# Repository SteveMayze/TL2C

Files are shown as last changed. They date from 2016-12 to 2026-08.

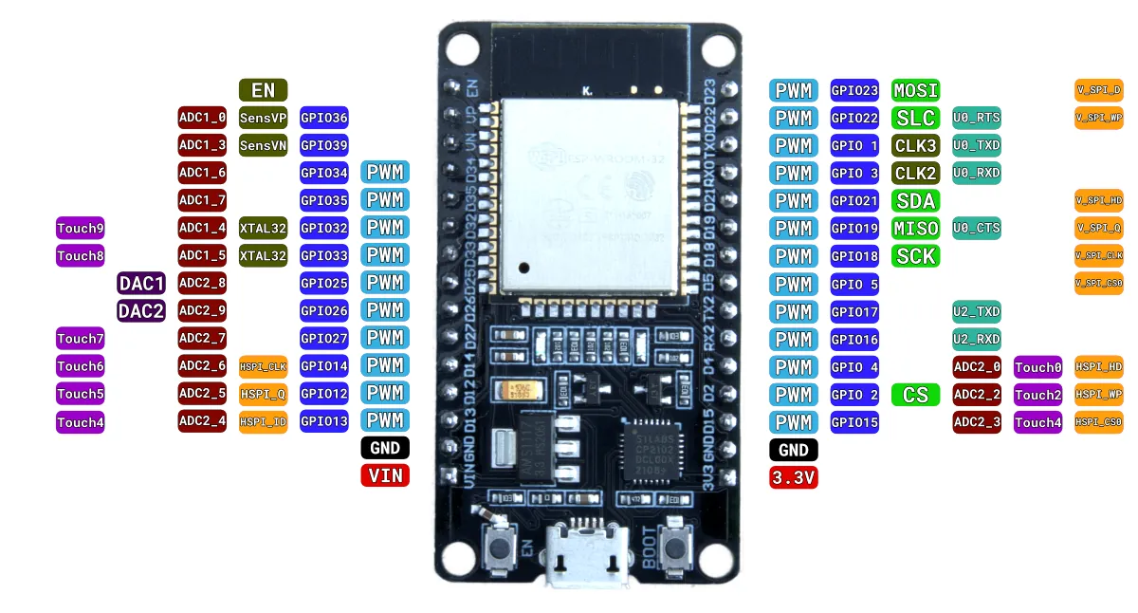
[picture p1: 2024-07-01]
doc/esp32/Node_MCU_ESP32_30Pin_pinout.webp

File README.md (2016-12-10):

# TL2C - Timed LED Lighting Control

## Introduction
This project is a I2C device to control up to three High Power LED drivers using three PIR13 motion controllers.

The LED drivers in question are already provided on my site and are the SLV 464110 10W 3-36V \(EAN: 4024163087155) constant current High Power LED drivers - as are the motion detectors [PIR13](http://www.elv.de/bewegungsmeldermodul-pir-13.html) modules from [ELV](http://www.elv.de).

The device will be designed around the ATTINY20-SSU micro-controller. The requirements being SPI for In System Programming, I2C to connect to the master device and GPIO for the three High Power LED drivers and the three PIR13 sensors.

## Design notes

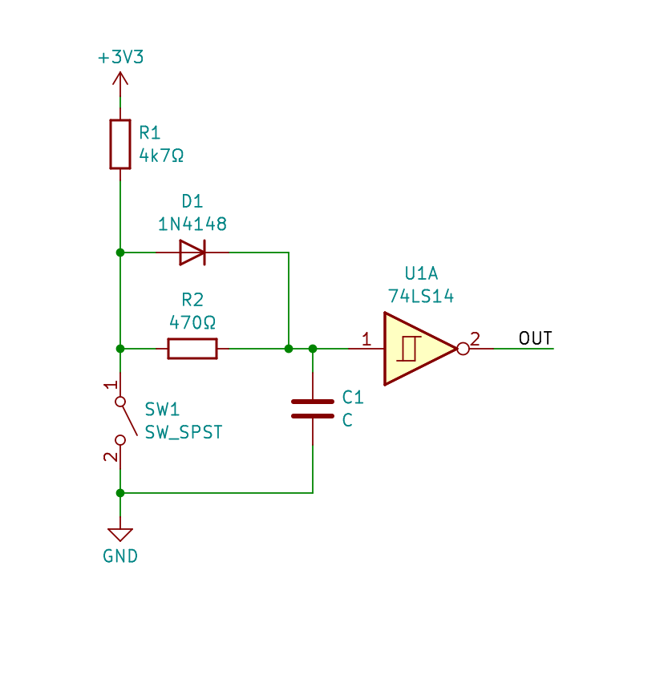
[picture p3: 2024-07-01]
doc/esp32/De-Bounce.png

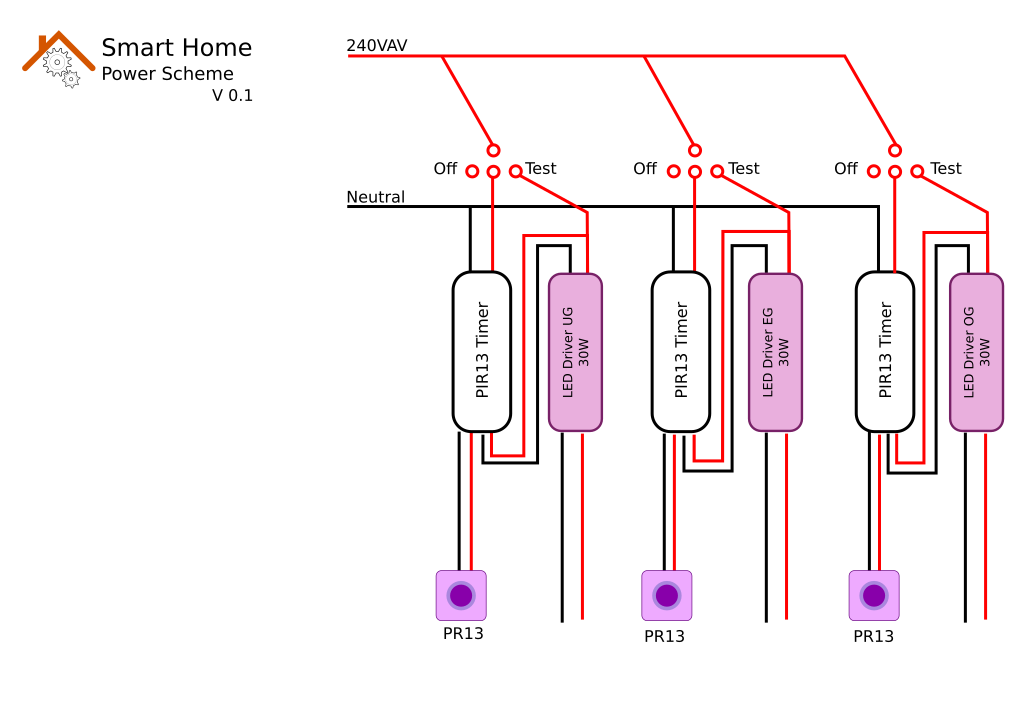
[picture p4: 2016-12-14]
doc/CurrentLEDControl.png

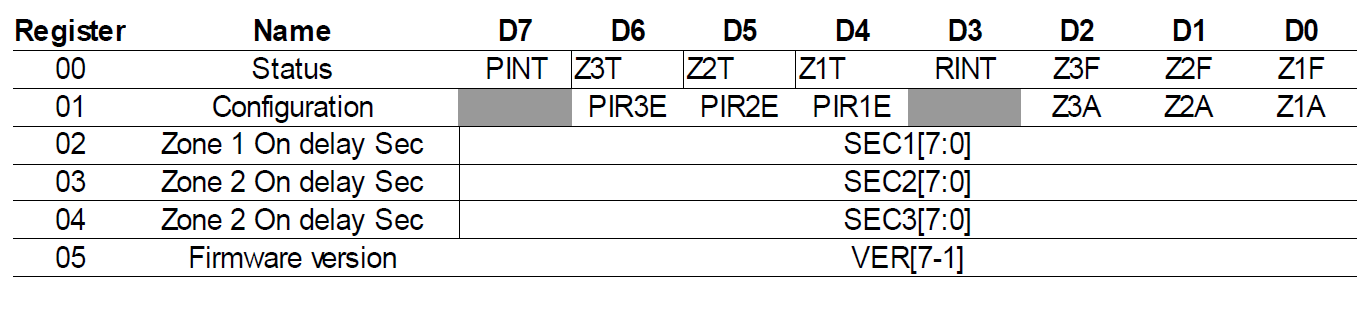
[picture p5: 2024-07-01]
doc/esp32/tl2c-registers.png

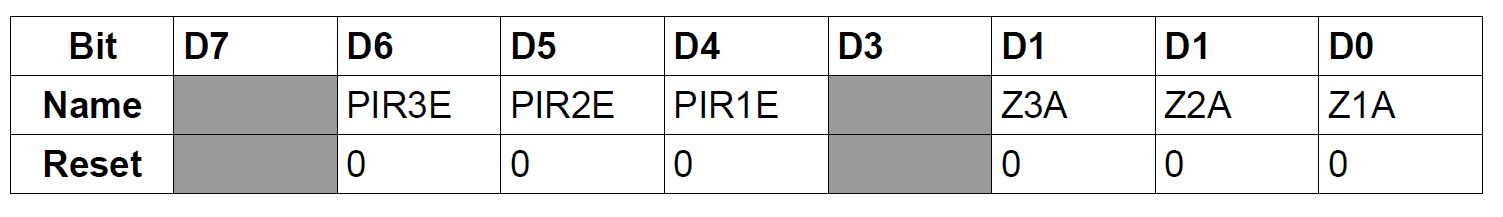
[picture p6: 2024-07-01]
doc/esp32/tl2c-register-1.png

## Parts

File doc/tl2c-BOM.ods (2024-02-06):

Reference | Quantity | Price | VAT | Cost | Conrad-PN | Digikey-PN | Reichelt-PN | MPN | ConradPN | Label
C101 C102 | 2 | 0.00052 | 1 | 0.00104
C201 | 1 | 0.00052 | 1 | 0.00052
C202 | 1 | 0.00052 | 1 | 0.00052
C203 | 1 | 0.27000 | 1 | 0.27000 | 450955 - 62 | N/A
C204 | 1 | 0.00052 | 1 | 0.00052
C501 C502 C503 | 3 | 0.00052 | 1 | 0.00156 |  |  |  | Value | Value
D101 | 1 | 0.13000 | 1 | 0.13000
D102 | 1 | 0.13000 | 1 | 0.13000
D103 | 1 | 0.13000 | 1 | 0.13000
D202 | 1 | 0.33000 | 1 | 0.33000
D404 D405 D406 | 3 | 0.17000 | 1 | 0.51000 | 564852 - 62 | 1N4148W-E3-18CT-ND
F101 | 1 | 0.40000 | 1 | 0.40000 |  |  | MIK-FLINK 0,5A
IC101 | 1 | 0.51000 | 1.19 | 0.60690 | 1267295 - 62 | ATTINY20-SSURCT-ND
 | 1 | 0.44000 | 1 | 0.44000
P101 | 2 | 0.26600 | 1 | 0.53200
Q301 Q302 Q303 Q401 Q402 Q403 | 6 | 0.23300 | 1 | 1.39800 | 162827 - 62 | IRLML2502GTRPBFCT-ND
R101 R307 R308 R309 R404 R405 R406 | 7 | 0.03663 | 1 | 0.25643
R103 R202 | 2 | 0.03663 | 1 | 0.07327
R104 R105 | 2 | 0.03663 | 1 | 0.07327
R106 R107 R108 R204 | 4 | 0.03663 | 1 | 0.14653
R301 R302 R303 | 3 | 0.03663 | 1 | 0.10990
R401 R402 R403 R407 R408 R409 | 6 | 0.03663 | 1 | 0.21980
REL101, REL102, REL103 | 3 | 2.14000 | 1 | 6.42000 | 504961 - 62
SW101 | 1 | 0.15520 | 1.19 | 0.18469
U201 | 1 | 0.88000 | 1 | 0.88000 | 1185937 - 62 | 497-8330-1-ND
U202 | 1 | 1.38000 | 1 | 1.38000 | 1261694 - 62 | 296-35483-1-ND
240VAC Board | 0.3333333333 | 45.75000 | 1 | 15.25000
Control Board | 0.3333333333 | 59.50000 | 1 | 19.83333
Enclosure | 1 | 4.75000 | 1 | 4.75000
RJ45 | 1 | 1.24000 | 2 | 2.48000
 |  |  |  | 56.94

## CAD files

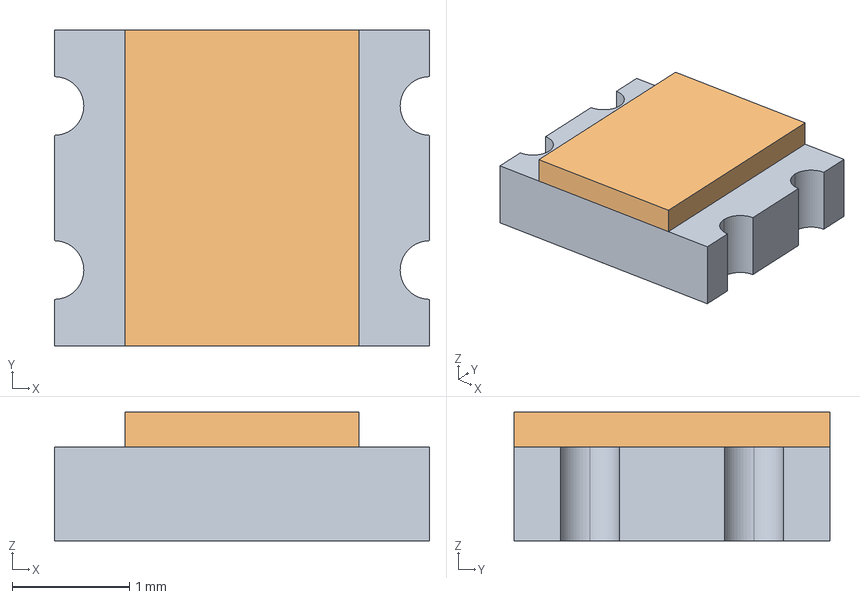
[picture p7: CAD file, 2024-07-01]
Models/15-22SURSYGC/15-22SURSYGC-B.FCStd
3.20 x 2.70 x 1.10 mm
Base
Lens

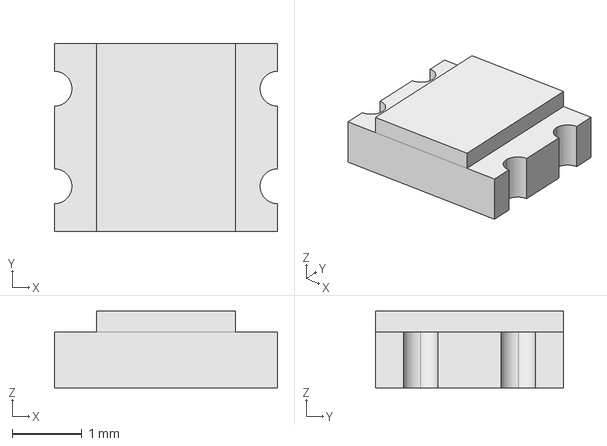
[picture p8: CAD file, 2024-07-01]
Models/15-22SURSYGC/15-22SURSYGC.FCStd
3.20 x 2.70 x 1.10 mm

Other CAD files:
Models/B3F_1150_Button.FCStd

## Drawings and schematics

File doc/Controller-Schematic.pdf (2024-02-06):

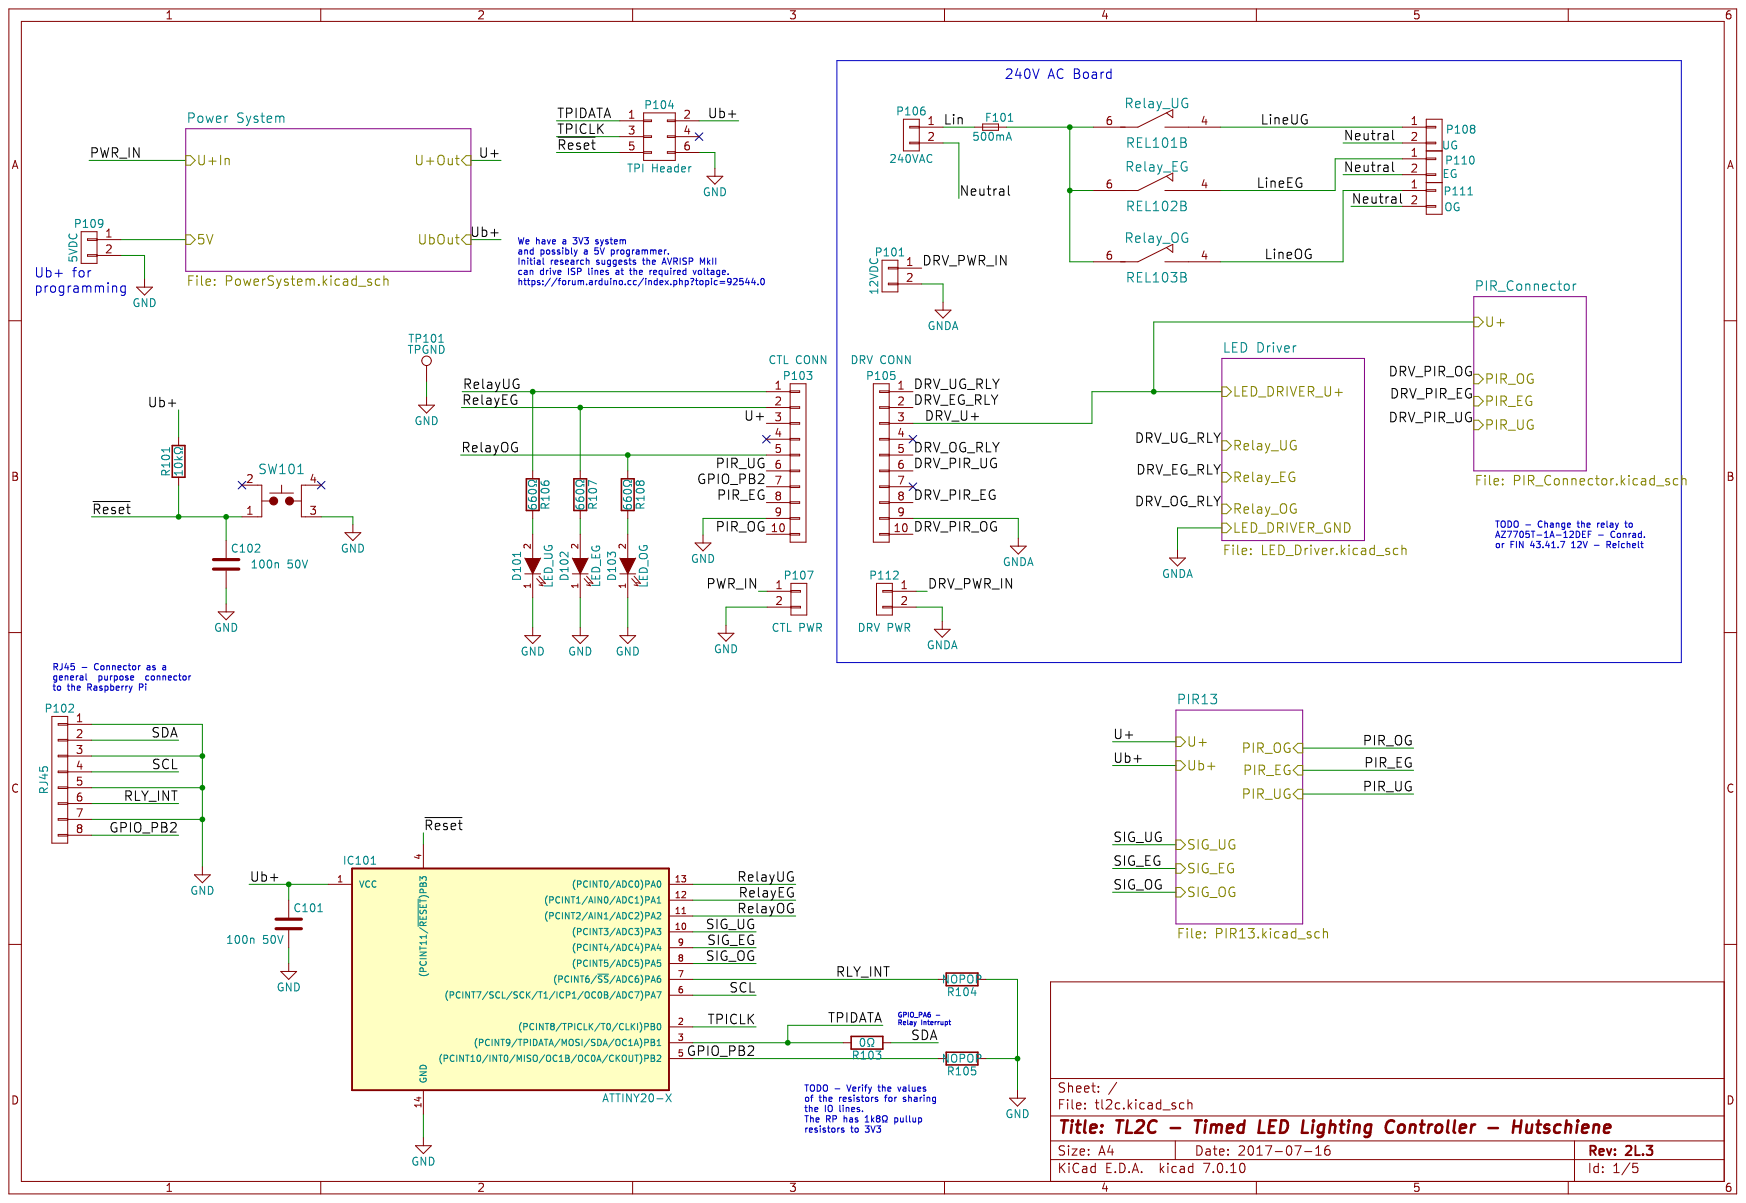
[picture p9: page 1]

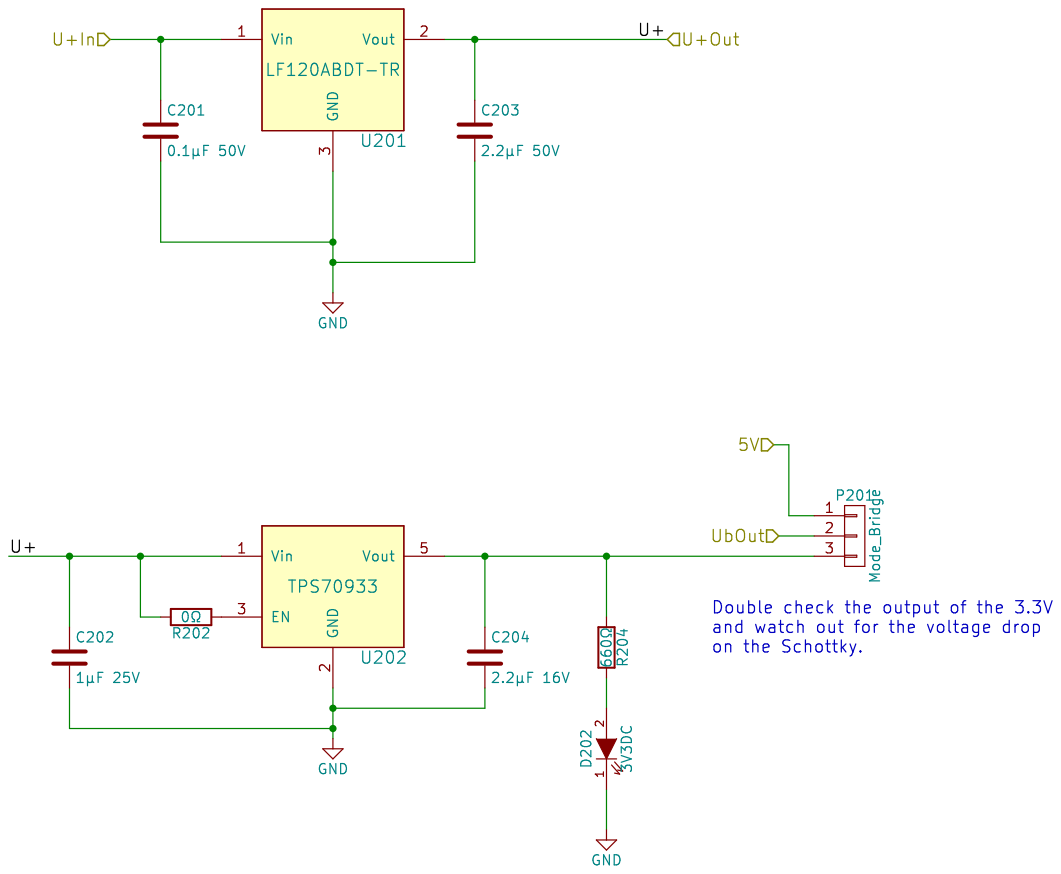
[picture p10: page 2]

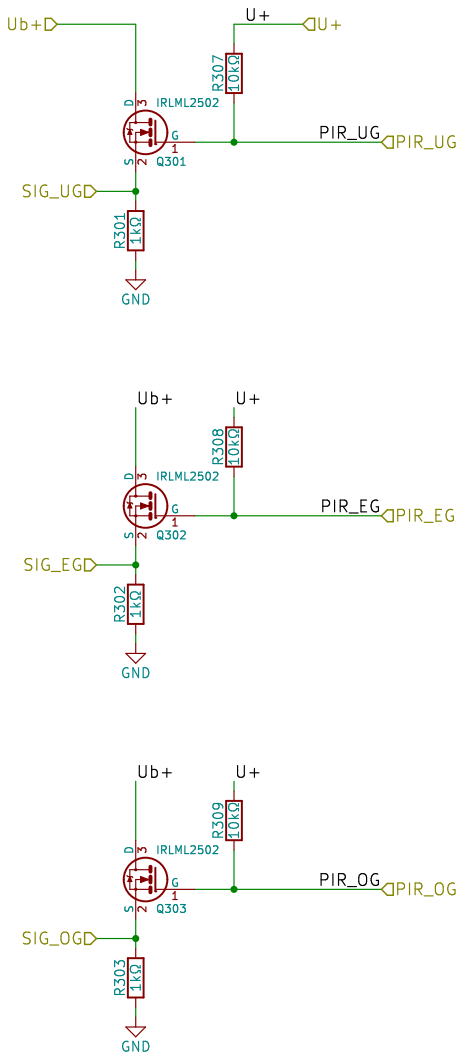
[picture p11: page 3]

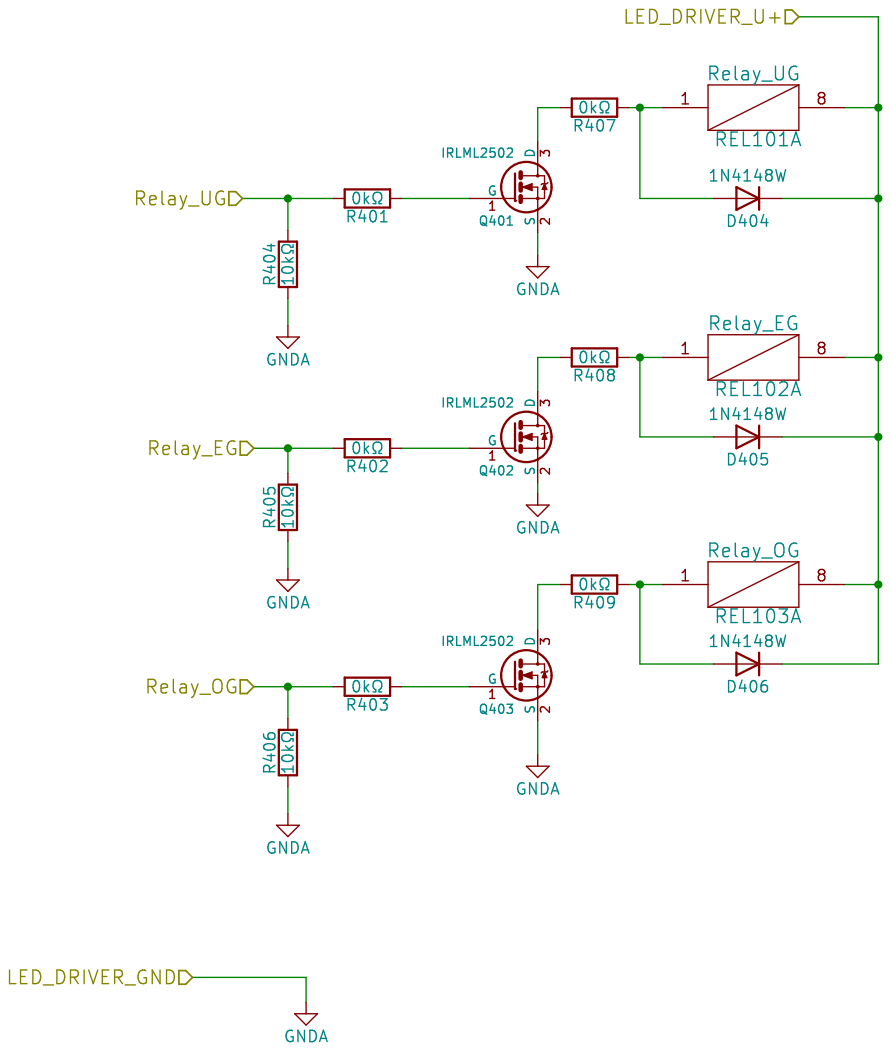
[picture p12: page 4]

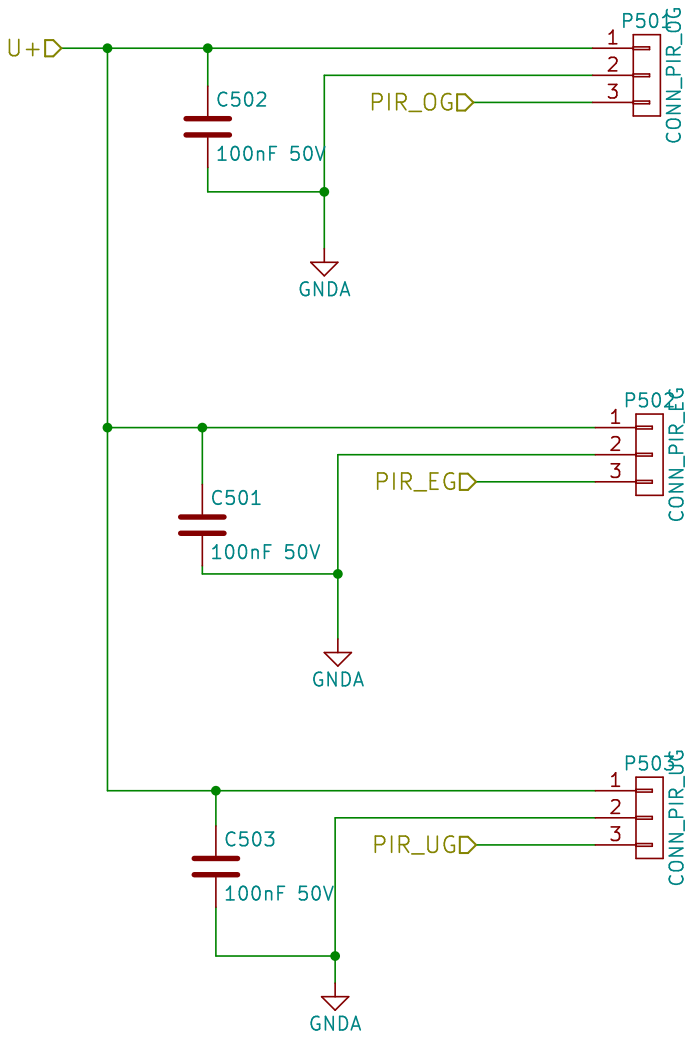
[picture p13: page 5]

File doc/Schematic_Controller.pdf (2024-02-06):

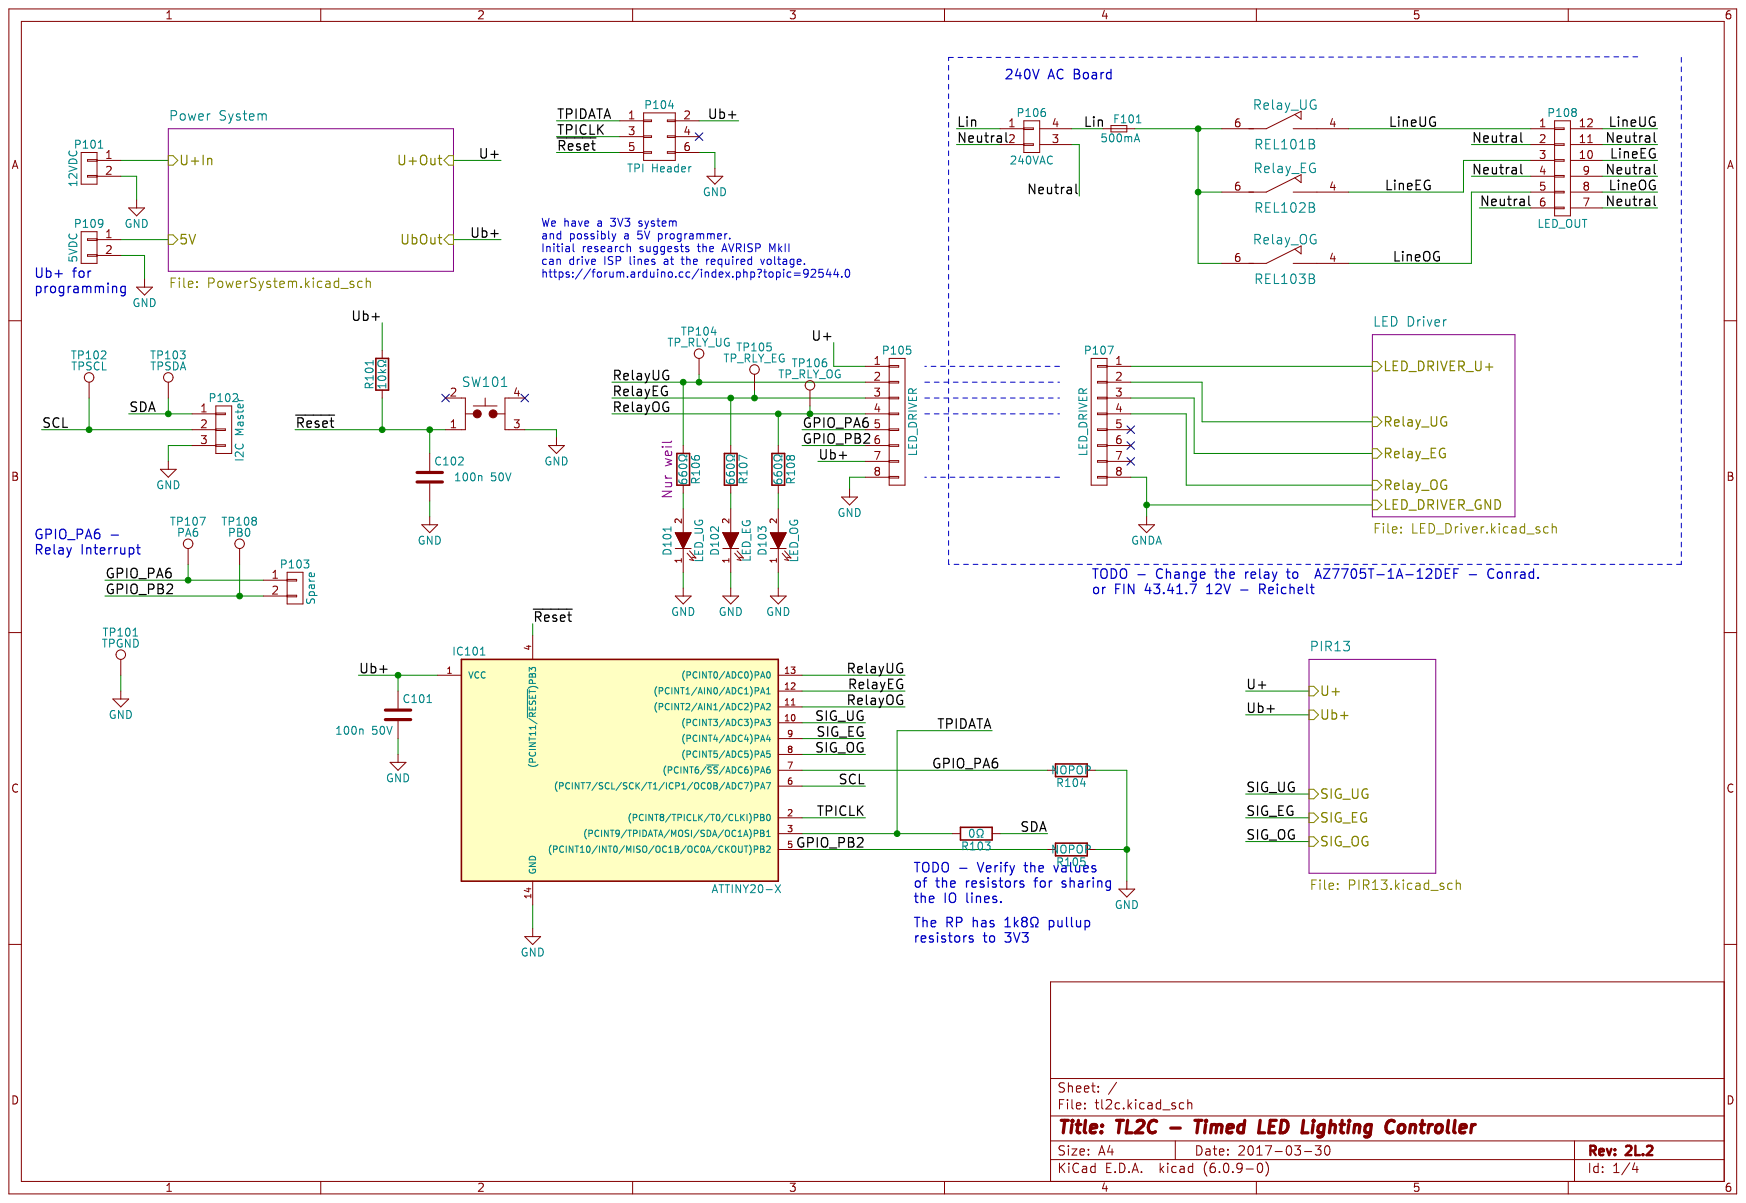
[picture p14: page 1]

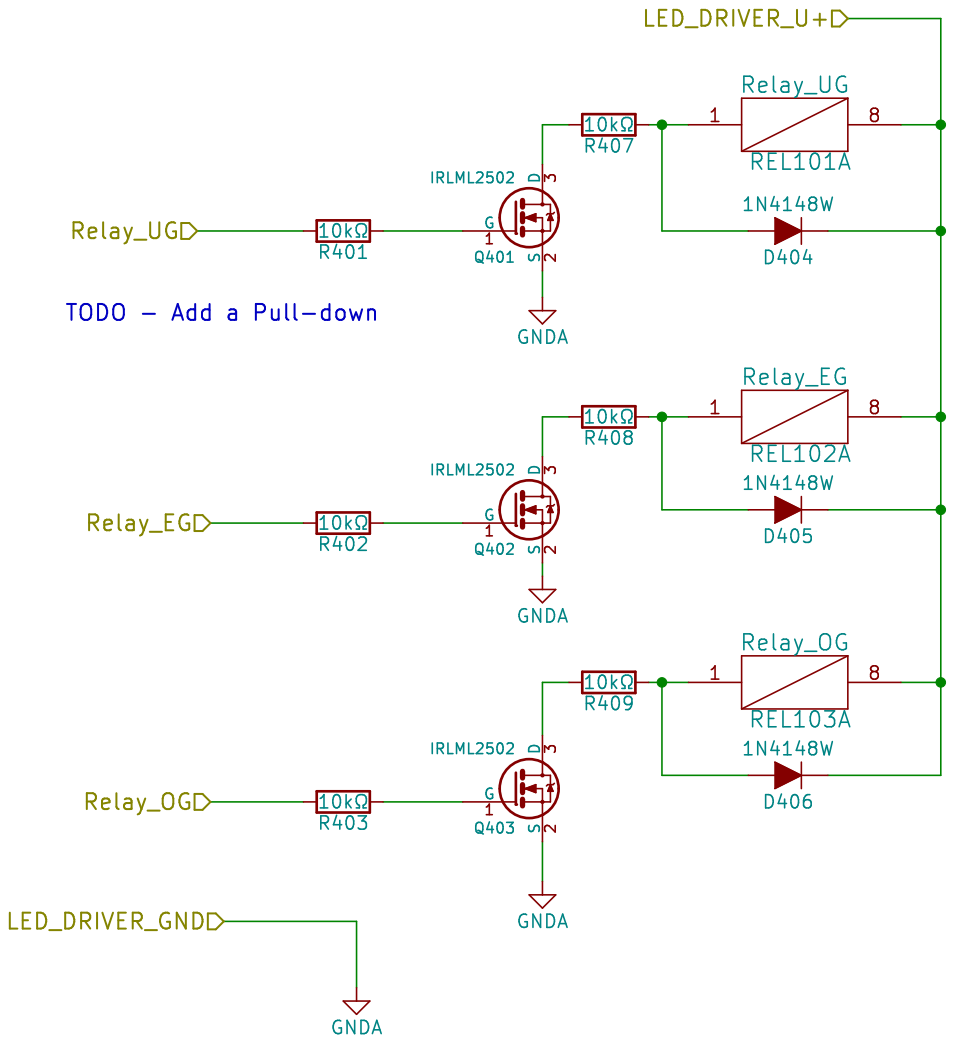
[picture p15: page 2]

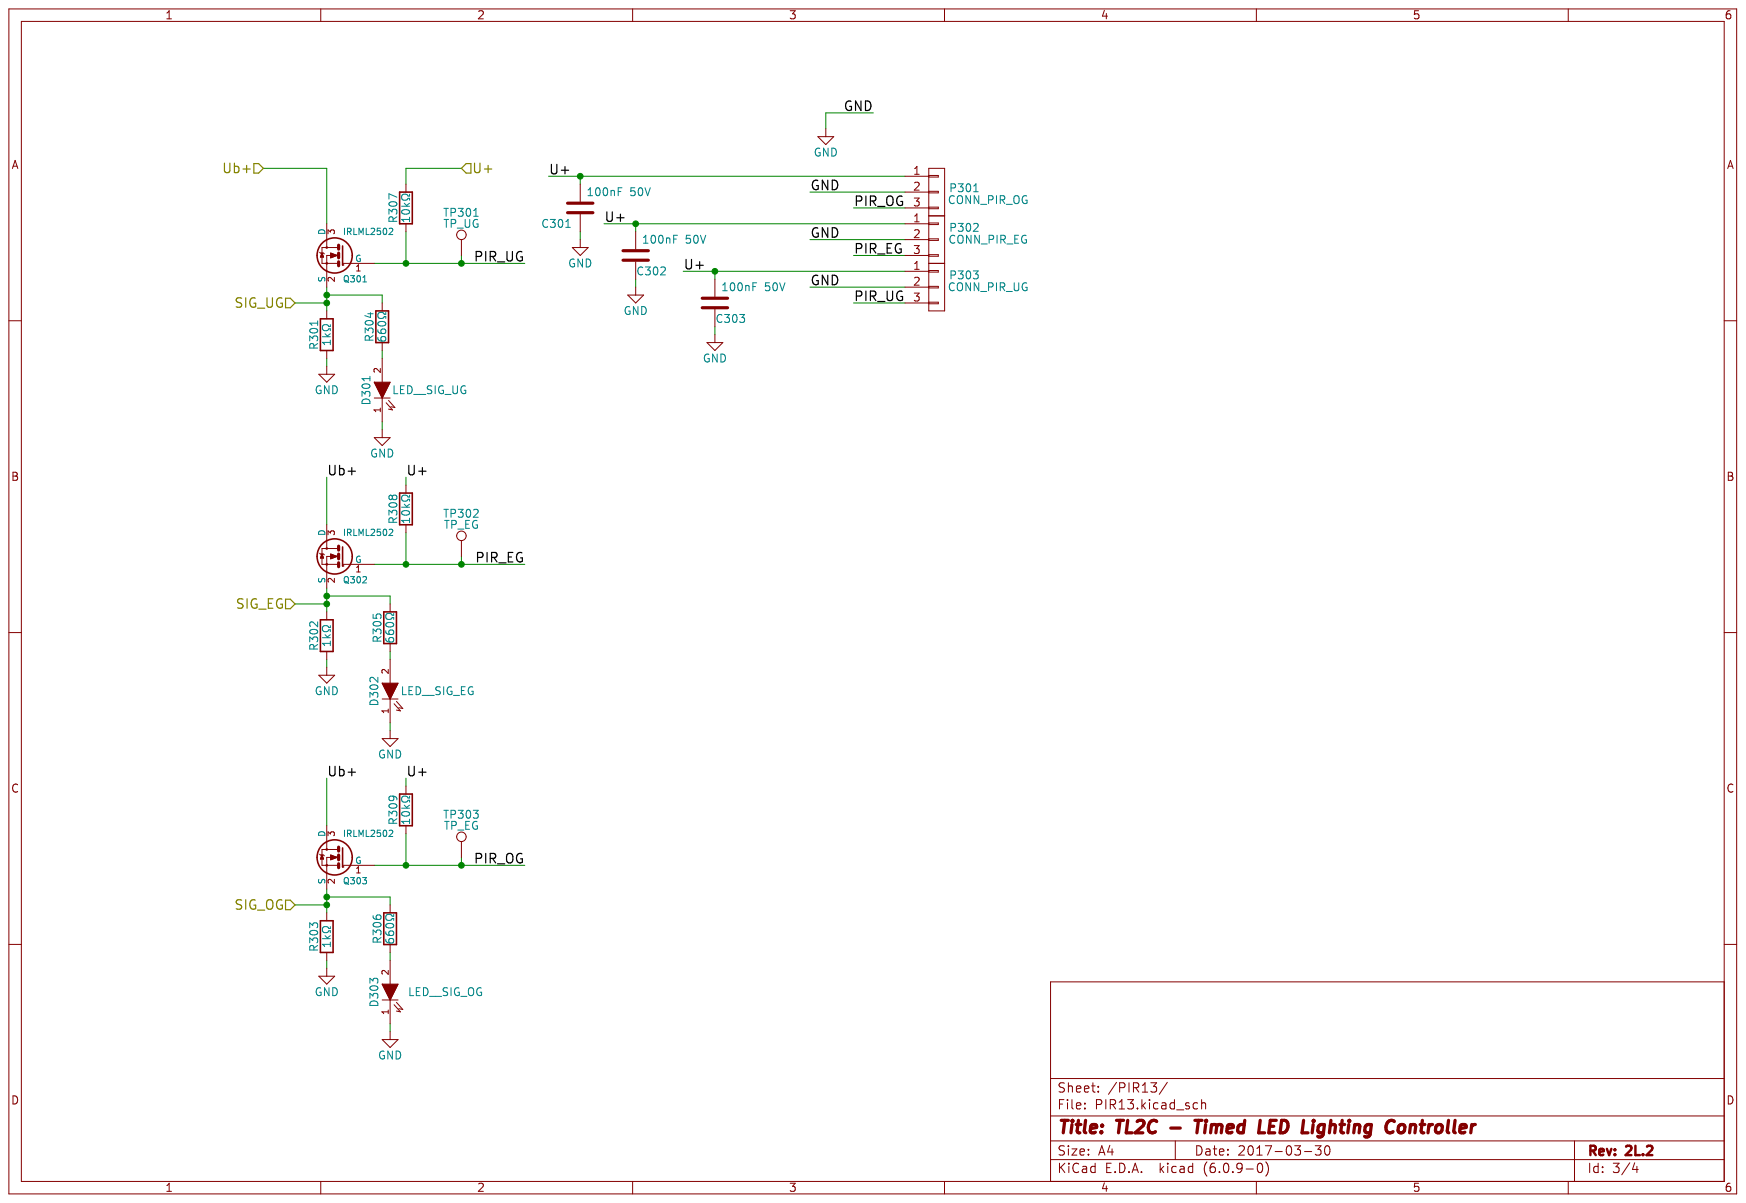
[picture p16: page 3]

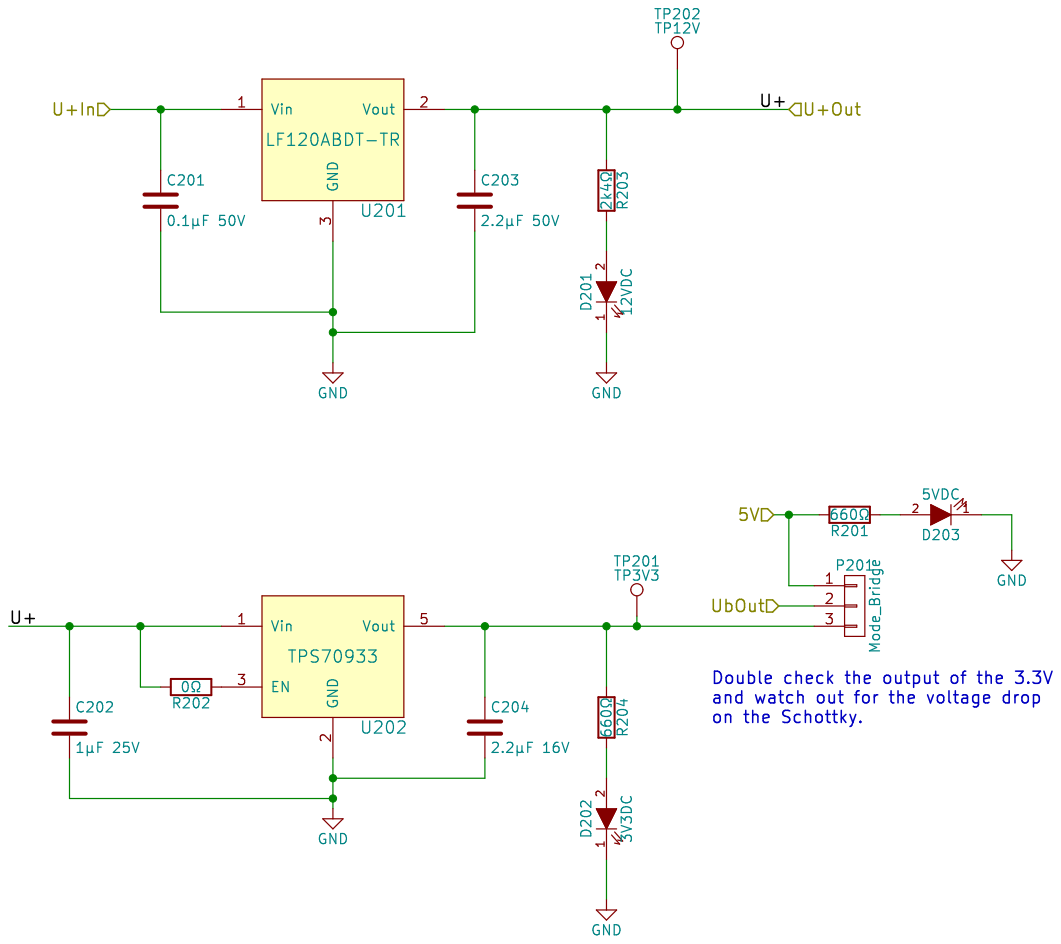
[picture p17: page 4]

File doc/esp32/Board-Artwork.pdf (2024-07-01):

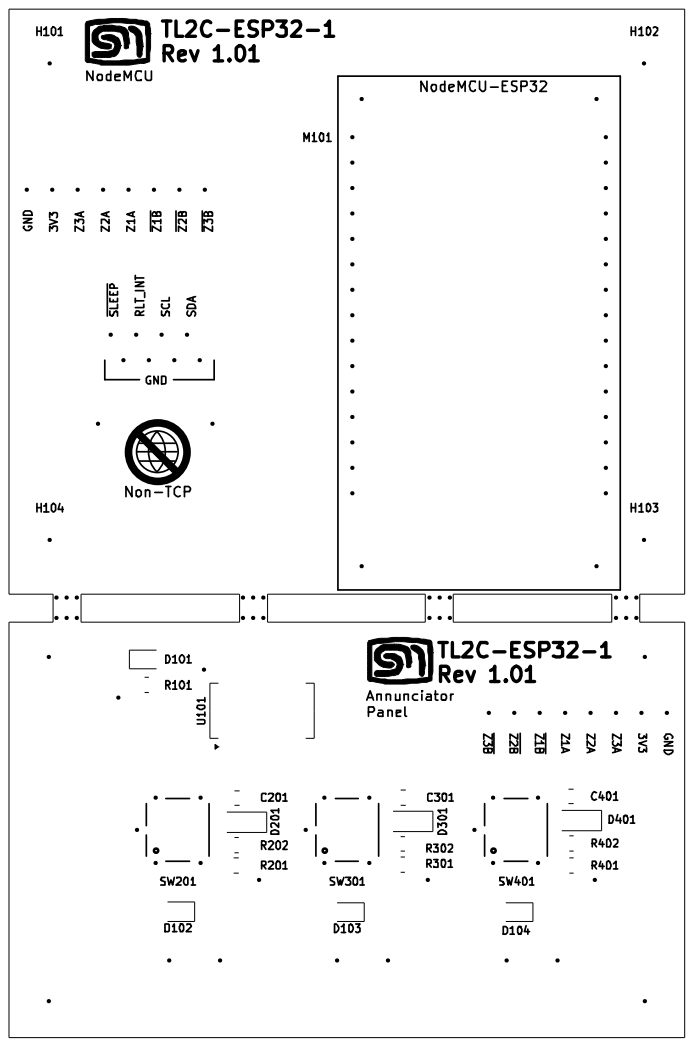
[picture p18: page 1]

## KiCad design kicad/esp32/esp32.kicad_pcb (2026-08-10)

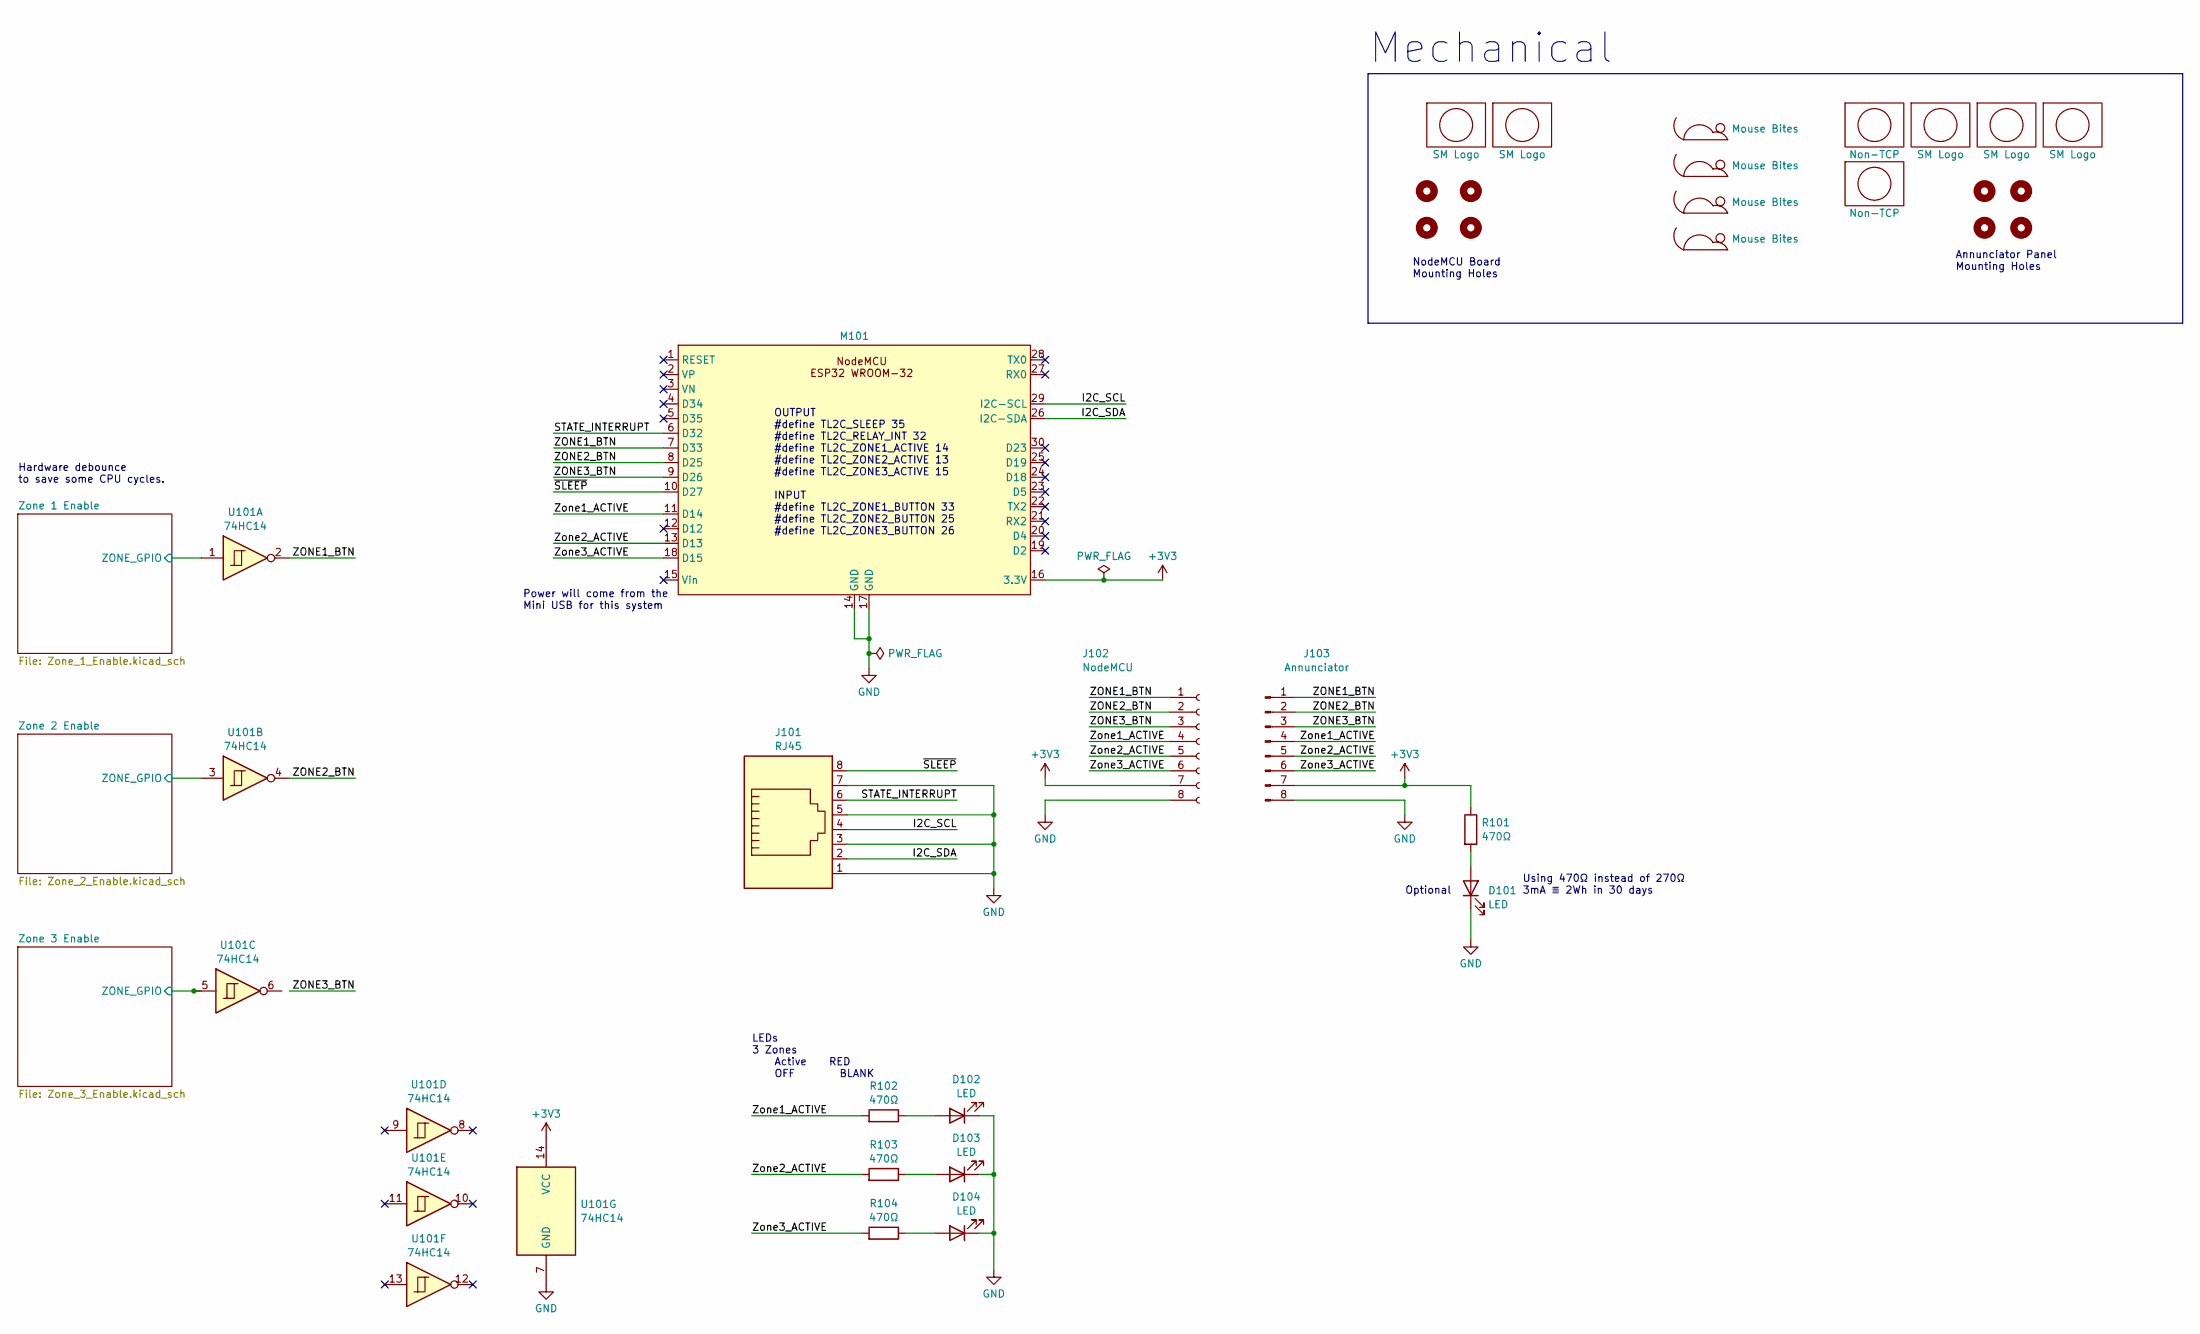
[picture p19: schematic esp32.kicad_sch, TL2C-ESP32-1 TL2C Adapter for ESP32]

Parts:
D101, D102, D103, D104: LED; LED_0805_2012Metric
H101, H102, H103, H104: MountingHole; MountingHole_2.1mm
H105, H106, H107, H108: Annunciator MountingHole; MountingHole_2.7mm_M2.5
J101: RJ45; RJ45_8P8C
J102: NodeMCU; PinSocket_1x08_P2.54mm_Vertical
J103: Annunciator; PinHeader_1x08_P2.54mm_Vertical
Lg101, Lg102, Lg106, Lg107: SM Logo; MyBasic_rounded_50_1
Lg103: SM Logo; MyBasic_rounded_50_1_USER5
Lg104, Lg105: Non-TCP; Non_TCP
M101: NodeMCU-ESP32
R101: 470Ω; R_0805_2012Metric
R102, R103, R104: 470Ω; R_Axial_DIN0207_L6.3mm_D2.5mm_P5.08mm_Vertical
U101: 74HC14; SO-14_5.3x10.2mm_P1.27mm
X101, X102, X103, X104: Mouse Bites; MouseBites

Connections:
+3V3: J102.7, J103.7, M101.16 (3.3V), R101.1, U101.14 (VCC); also elsewhere on the board
/I2C_SCL: J101.4, M101.29 (I2C-SCL)
/I2C_SDA: J101.2, M101.26 (I2C-SDA)
/STATE_INTERRUPT: J101.6, M101.6 (D32)
/ZONE1_BTN: J102.1, J103.1, M101.7 (D33), U101.2
/ZONE2_BTN: J102.2, J103.2, M101.8 (D25), U101.4
/ZONE3_BTN: J102.3, J103.3, M101.9 (D26)
/Zone1_ACTIVE: J102.4, J103.4, M101.11 (D14), R102.2
/Zone2_ACTIVE: J102.5, J103.5, M101.13 (D13), R103.2
/Zone3_ACTIVE: J102.6, J103.6, M101.18 (D15), R104.2
/Zone 1 Enable/ZONE_GPIO: U101.1; also elsewhere on the board
/Zone 2 Enable/ZONE_GPIO: U101.3; also elsewhere on the board
/Zone 3 Enable/ZONE_GPIO: U101.5; also elsewhere on the board
/~SLEEP: J101.8, M101.10 (D27)
GND: D101.1 (K), D102.1 (K), D103.1 (K), D104.1 (K), J101.1, J101.3, J101.5, J101.7, J102.8, J103.8, M101.14 (GND), M101.17 (GND), U101.7 (GND); also elsewhere on the board
unnamed: D101.2 (A), R101.2
unnamed: D102.2 (A), R102.1
unnamed: D103.2 (A), R103.1
unnamed: D104.2 (A), R104.1

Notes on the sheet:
LEDs 3 Zones Active RED OFF BLANK
Mechanical
OUTPUT #define TL2C_SLEEP 35 #define TL2C_RELAY_INT 32 #define TL2C_ZONE1_ACTIVE 14 #define TL2C_ZONE2_ACTIVE 13 #define TL2C_ZONE3_ACTIVE 15 INPUT #define TL2C_ZONE1_BUTTON 33 #define TL2C_ZONE2_BUTTON 25 #define TL2C_ZONE3_BUTTON 26
Using 470Ω instead of 270Ω 3mA ≣ 2Wh in 30 days
Power will come from the Mini USB for this system
NodeMCU Board Mounting Holes
Hardware debounce to save some CPU cycles.
Optional
Annunciator Panel Mounting Holes

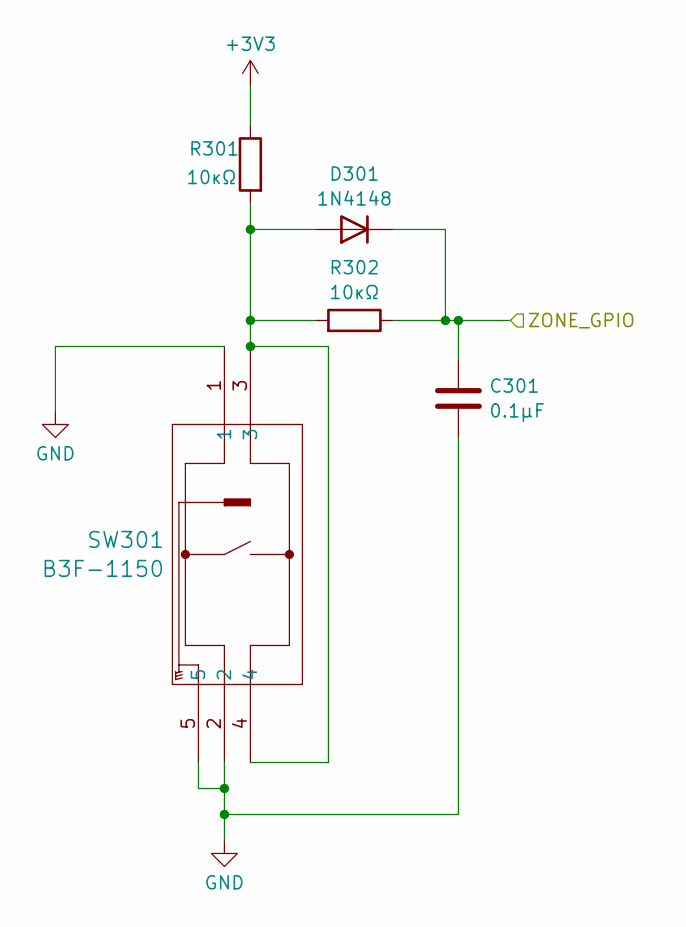
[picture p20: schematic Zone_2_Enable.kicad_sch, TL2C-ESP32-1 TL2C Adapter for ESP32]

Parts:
C301: 0.1μF; C_0805_2012Metric
D301: 1N4148; D_SOD-123
R301, R302: 10κΩ; R_0805_2012Metric
SW301: B3F-1150; SW_B3F-1150_OMR

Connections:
+3V3: R301.1; also elsewhere on the board
/Zone 2 Enable/ZONE_GPIO: C301.1, D301.1 (K), R302.1; also elsewhere on the board
GND: C301.2, SW301.1, SW301.2, SW301.5; also elsewhere on the board
unnamed: D301.2 (A), R301.2, R302.2, SW301.3, SW301.4

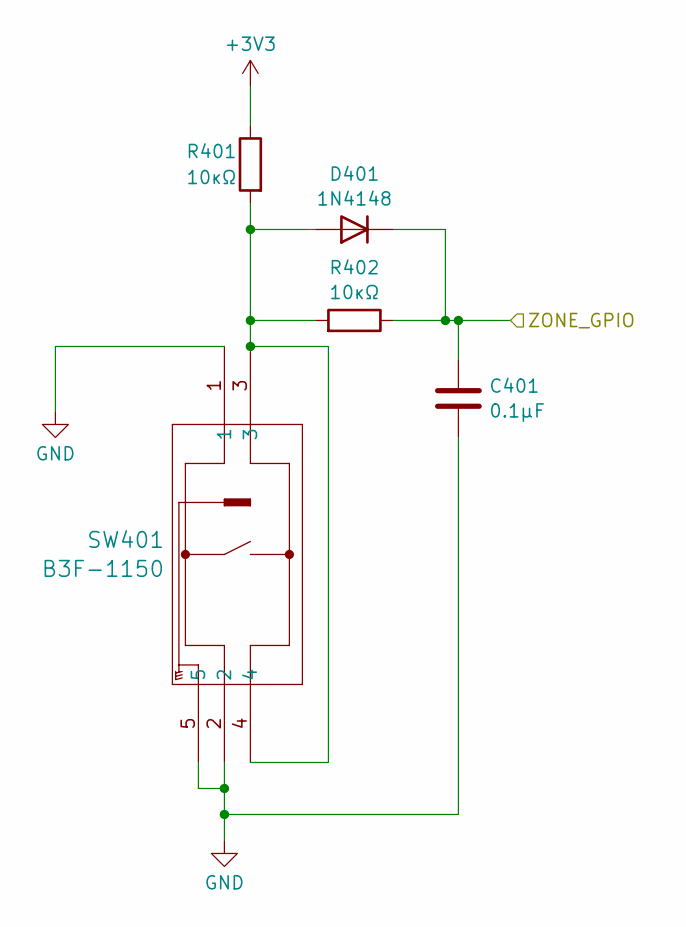
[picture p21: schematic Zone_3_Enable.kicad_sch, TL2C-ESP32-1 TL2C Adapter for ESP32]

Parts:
C401: 0.1μF; C_0805_2012Metric
D401: 1N4148; D_SOD-123
R401, R402: 10κΩ; R_0805_2012Metric
SW401: B3F-1150; SW_B3F-1150_OMR

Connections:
+3V3: R401.1; also elsewhere on the board
/Zone 3 Enable/ZONE_GPIO: C401.1, D401.1 (K), R402.1; also elsewhere on the board
GND: C401.2, SW401.1, SW401.2, SW401.5; also elsewhere on the board
unnamed: D401.2 (A), R401.2, R402.2, SW401.3, SW401.4

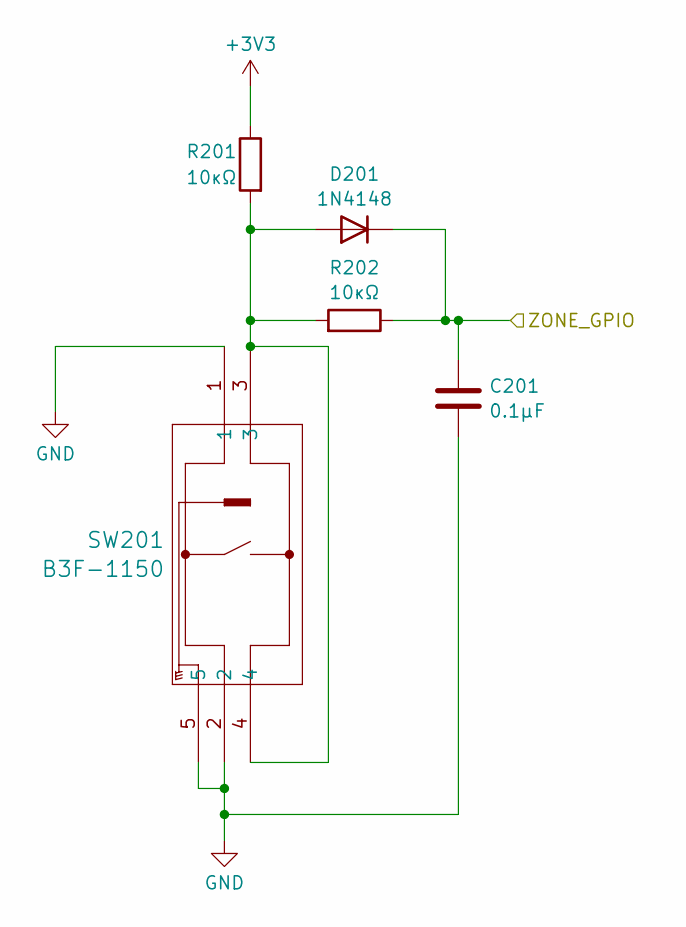
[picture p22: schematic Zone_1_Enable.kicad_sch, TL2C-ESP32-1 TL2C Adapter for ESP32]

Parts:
C201: 0.1μF; C_0805_2012Metric
D201: 1N4148; D_SOD-123
R201, R202: 10κΩ; R_0805_2012Metric
SW201: B3F-1150; SW_B3F-1150_OMR

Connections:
+3V3: R201.1; also elsewhere on the board
/Zone 1 Enable/ZONE_GPIO: C201.1, D201.1 (K), R202.1; also elsewhere on the board
GND: C201.2, SW201.1, SW201.2, SW201.5; also elsewhere on the board
unnamed: D201.2 (A), R201.2, R202.2, SW201.3, SW201.4

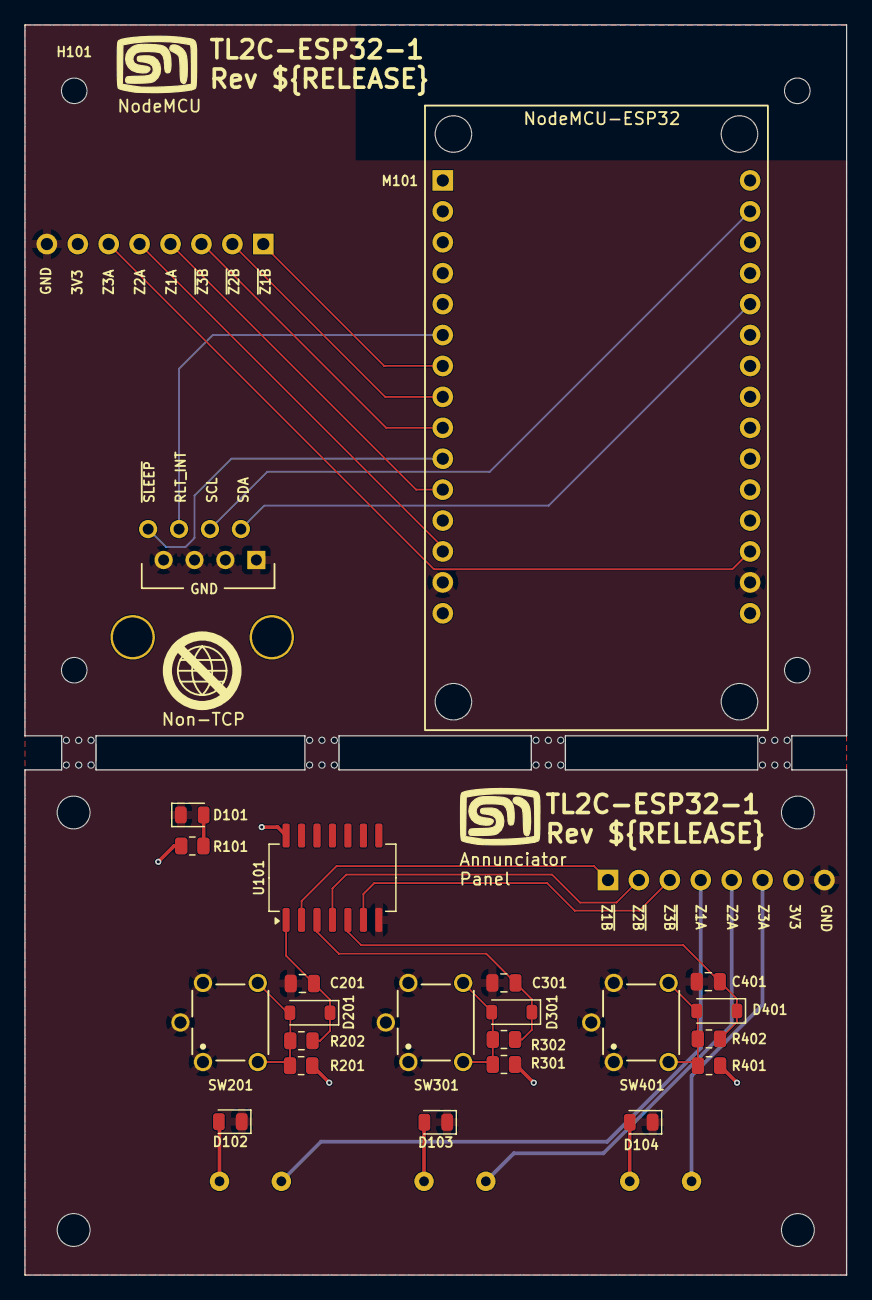
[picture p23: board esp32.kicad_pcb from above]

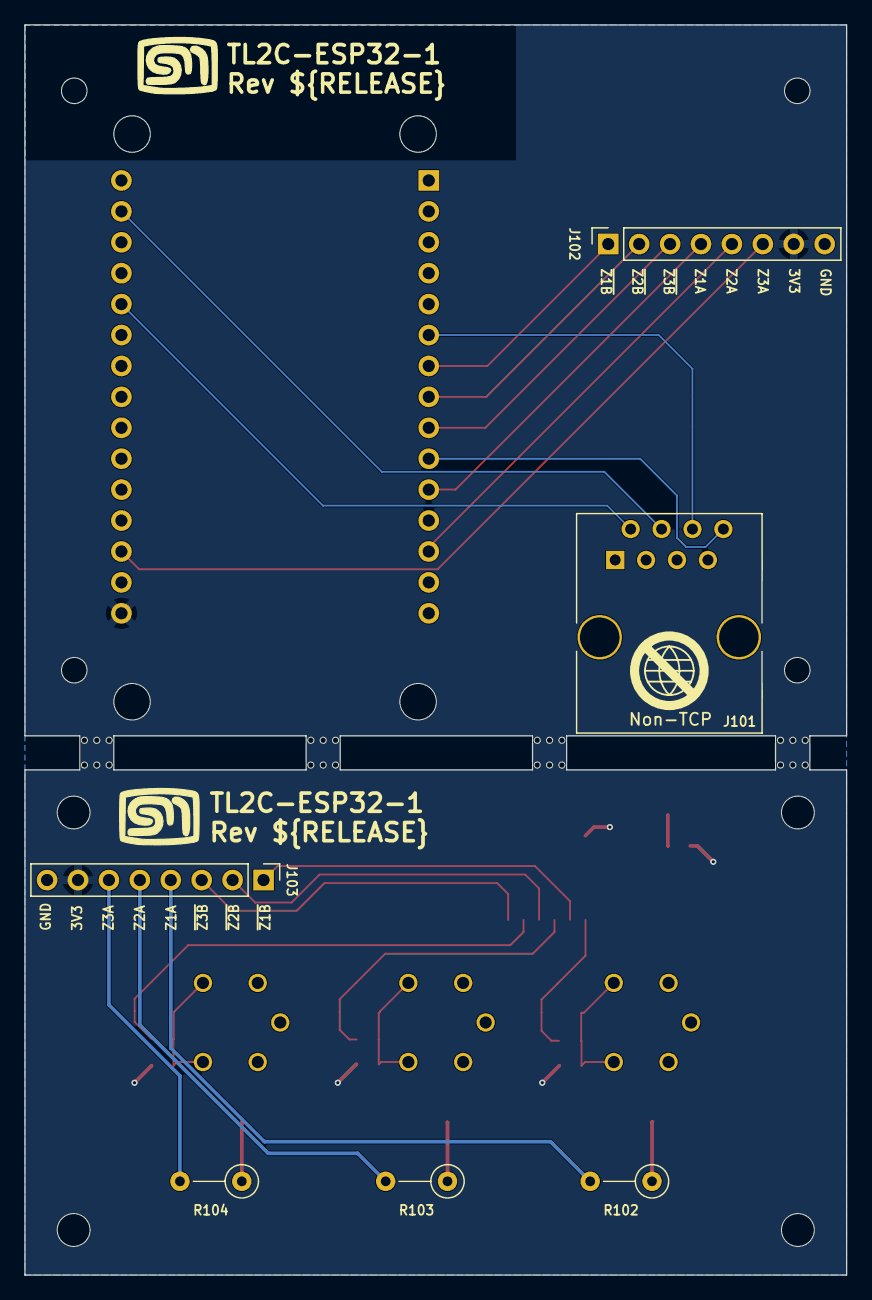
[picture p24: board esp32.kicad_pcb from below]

Board: 2 copper layers, 67.5 x 102.7 mm, 47 parts (9 on the bottom side), 22 nets.

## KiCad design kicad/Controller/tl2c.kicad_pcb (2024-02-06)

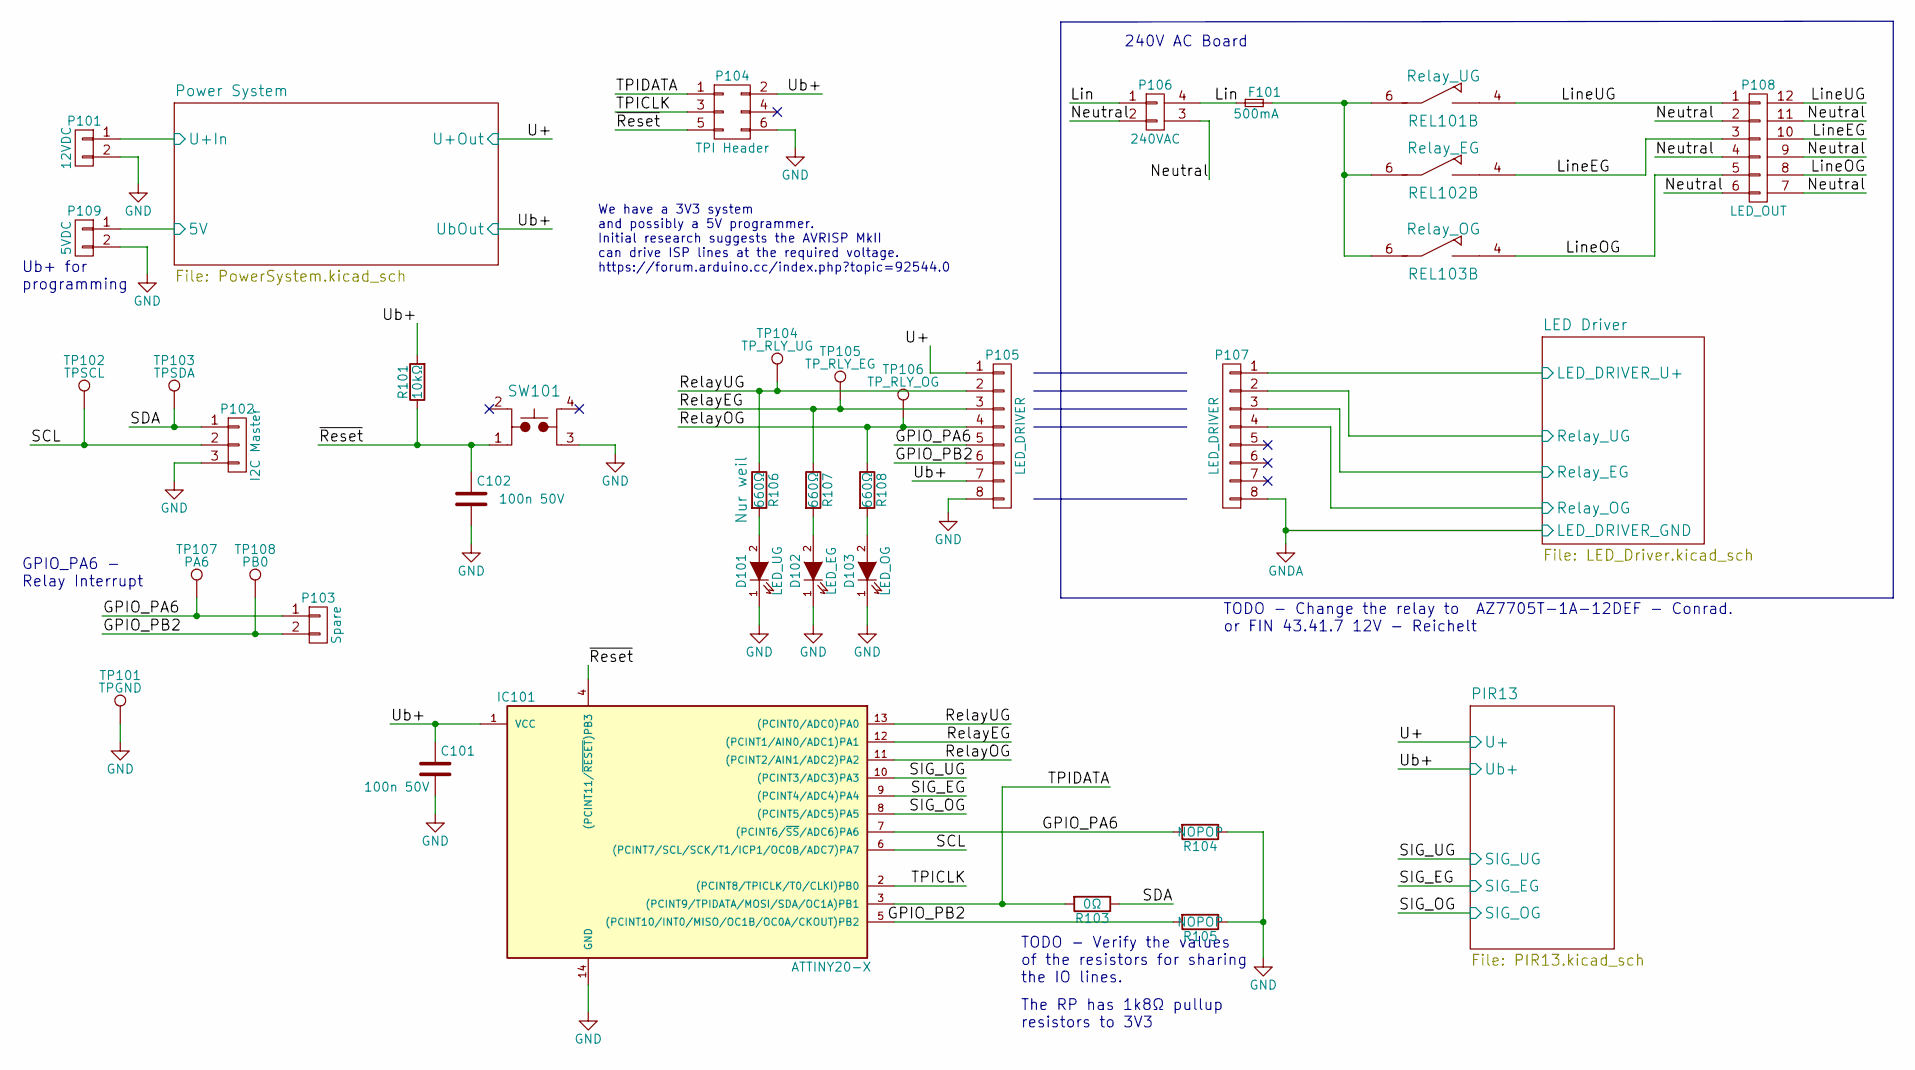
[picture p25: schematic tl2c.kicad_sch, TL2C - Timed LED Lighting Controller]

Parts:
C101, C102: 100n 50V; C_0805
D101: LED_UG; LED_0805
D102: LED_EG; LED_0805
D103: LED_OG; LED_0805
F101: 500mA; Fuse_TE5_Littlefuse-ESKA_887_O14; Digikey-PN Value
IC101: ATTINY20-X; SOIC-14_3.9x8.7mm_Pitch1.27mm; Digikey-PN ATTINY20-SSURCT-ND
P101: 12VDC; Pin_Header_Straight_1x02; Digikey-PN Value
P102: I2C Master; Spring_Terminal_Block_1_x_3; Digikey-PN Value
P103: Spare; Pin_Header_Straight_1x02; Digikey-PN Value
P104: TPI Header; TC2030-IDC-FP_ISP_Connector; Digikey-PN Value
P105, P107: LED_DRIVER; Pin_Header_Straight_1x08_Pitch2.54mm; Digikey-PN Value
P106: 240VAC; Spring_Terminal_Block_1_x_2_5mm; Digikey-PN Value
P108: LED_OUT; Spring_Terminal_Block_1_x_6_5mm; Digikey-PN Value
P109: 5VDC; Pin_Header_Straight_1x02_Pitch2.54mm; Digikey-PN Value
R101: 10kΩ; R_0805
R103: 0Ω; R_0805
R104, R105: NOPOP; R_0805
R106, R107, R108: 660Ω; R_0805
REL101: Relay_UG; JW1AFSN-12-F; Digikey-PN Value
REL102: Relay_EG; JW1AFSN-12-F; Digikey-PN Value
REL103: Relay_OG; JW1AFSN-12-F; Digikey-PN Value
SW101: TL3315NF160Q; PTS525SM15SMTR2LFS; Digikey-PN Value
TP101: TPGND; Measurement_Point_Round-SMD-Pad_Small
TP102: TPSCL; Measurement_Point_Round-SMD-Pad_Small
TP103: TPSDA; Measurement_Point_Round-SMD-Pad_Small
TP104: TP_RLY_UG; Measurement_Point_Round-SMD-Pad_Small
TP105: TP_RLY_EG; Measurement_Point_Round-SMD-Pad_Small
TP106: TP_RLY_OG; Measurement_Point_Round-SMD-Pad_Small
TP107: PA6; Measurement_Point_Round-SMD-Pad_Small
TP108: PB0; Measurement_Point_Round-SMD-Pad_Small

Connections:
/GPIO_PA6: IC101.7 ((PCINT6/~SS/ADC6)PA6), P103.1, P105.5, R104.2, TP107.1
/GPIO_PB2: IC101.5 ((PCINT10/INT0/MISO/OC1B/OC0A/CKOUT)PB2), P103.2, P105.6, R105.2, TP108.1
/LED Driver/LED_DRIVER_U+: P107.1; also elsewhere on the board
/LED Driver/Relay_EG: P107.3; also elsewhere on the board
/LED Driver/Relay_OG: P107.4; also elsewhere on the board
/LED Driver/Relay_UG: P107.2; also elsewhere on the board
/Lin: F101.1, P106.1, P106.4
/LineEG: P108.3, P108.10, REL102.4
/LineOG: P108.5, P108.8, REL103.4
/LineUG: P108.1, P108.12, REL101.4
/Neutral: P106.2, P106.3, P108.2, P108.4, P108.6, P108.7, P108.9, P108.11
/PIR13/SIG_EG: IC101.9 ((PCINT4/ADC4)PA4); also elsewhere on the board
/PIR13/SIG_OG: IC101.8 ((PCINT5/ADC5)PA5); also elsewhere on the board
/PIR13/SIG_UG: IC101.10 ((PCINT3/ADC3)PA3); also elsewhere on the board
/PIR13/U+: P105.1; also elsewhere on the board
/PIR13/Ub+: C101.1, IC101.1 (VCC), P104.2, P105.7, R101.2; also elsewhere on the board
/Power System/5V: P109.1; also elsewhere on the board
/Power System/U+In: P101.1; also elsewhere on the board
/RelayEG: IC101.12 ((PCINT1/AIN0/ADC1)PA1), P105.3, R107.1, TP105.1
/RelayOG: IC101.11 ((PCINT2/AIN1/ADC2)PA2), P105.4, R108.1, TP106.1
/RelayUG: IC101.13 ((PCINT0/ADC0)PA0), P105.2, R106.1, TP104.1
/SCL: IC101.6 ((PCINT7/SCL/SCK/T1/ICP1/OC0B/ADC7)PA7), P102.2, TP102.1
/SDA: P102.1, R103.1, TP103.1
/TPICLK: IC101.2 ((PCINT8/TPICLK/T0/CLKI)PB0), P104.3
/TPIDATA: IC101.3 ((PCINT9/TPIDATA/MOSI/SDA/OC1A)PB1), P104.1, R103.2
/~Reset: C102.1, IC101.4 ((PCINT11/~RESET)PB3), P104.5, R101.1, SW101.1
GND: C101.2, C102.2, D101.1 (K), D102.1 (K), D103.1 (K), IC101.14 (GND), P101.2, P102.3, P104.6, P105.8, P109.2, R104.1, R105.1, SW101.3, TP101.1; also elsewhere on the board
GNDA: P107.8; also elsewhere on the board
unnamed: D101.2 (A), R106.2
unnamed: D102.2 (A), R107.2
unnamed: D103.2 (A), R108.2
unnamed: F101.2, REL101.6, REL102.6, REL103.6

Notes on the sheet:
TODO - Verify the values of the resistors for sharing the IO lines.
TODO - Change the relay to AZ7705T-1A-12DEF - Conrad. or FIN 43.41.7 12V - Reichelt
The RP has 1k8Ω pullup resistors to 3V3
GPIO_PA6 - Relay Interrupt
We have a 3V3 system and possibly a 5V programmer. Initial research suggests the AVRISP MkII can drive ISP lines at the required voltage. https://forum.arduino.cc/index.php?topic=92544.0
Ub+ for programming
240V AC Board

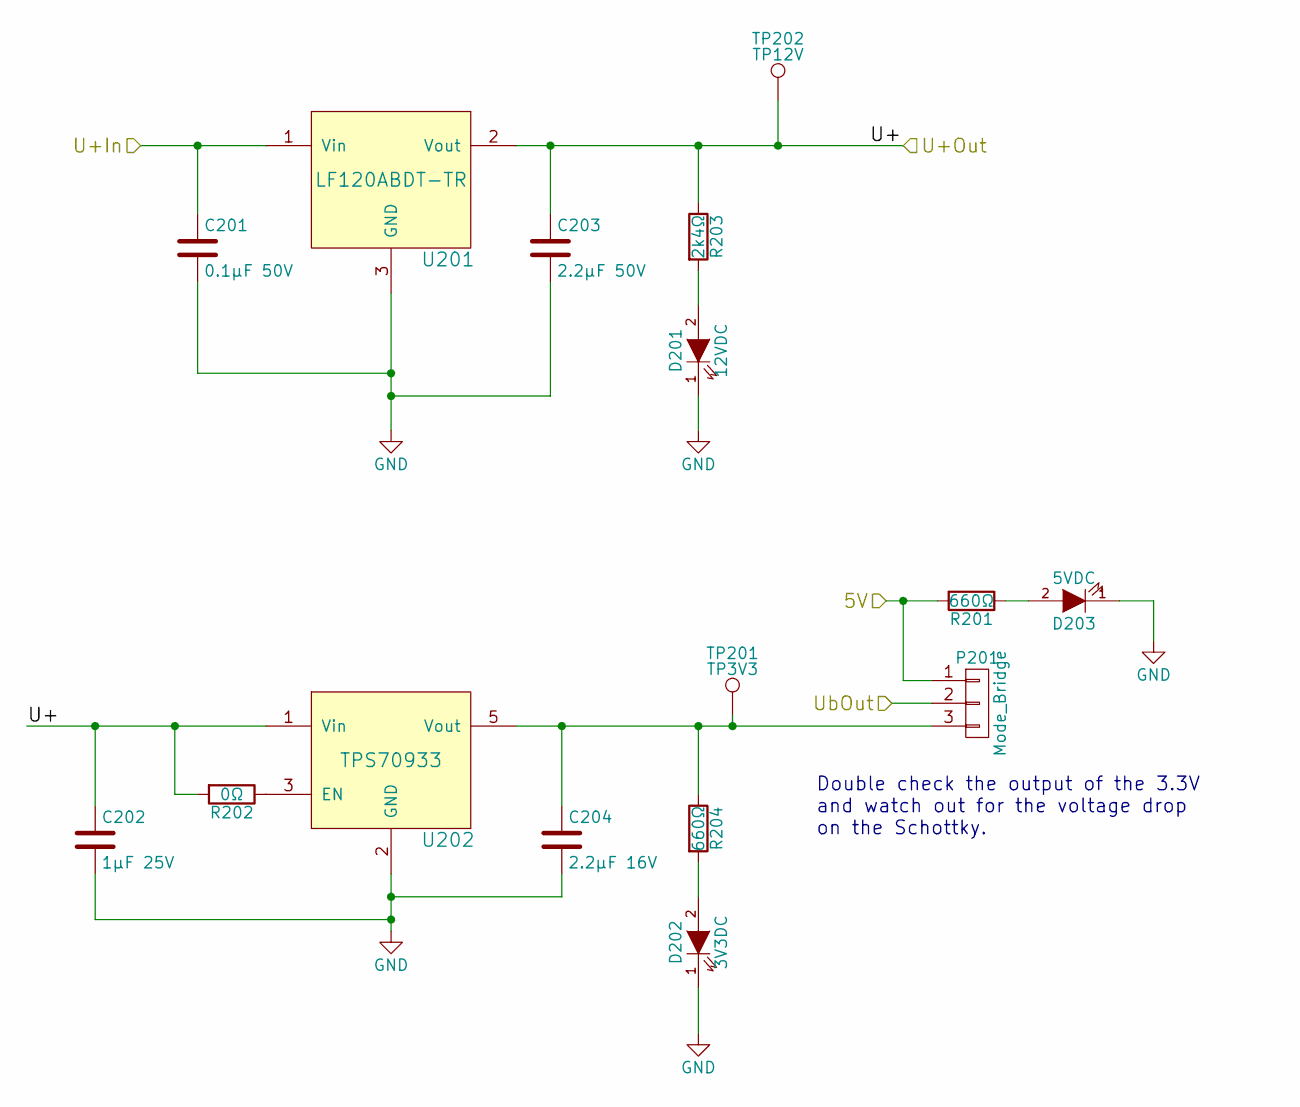
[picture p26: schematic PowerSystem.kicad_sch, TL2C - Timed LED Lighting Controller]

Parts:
C201: 0.1μF 50V; C_0805
C202: 1μF 25V; C_1210; Digikey-PN Value
C203: 2.2μF 50V; C_1206; Digikey-PN N/A
C204: 2.2μF 16V; C_1210; Digikey-PN Value
D201: 12VDC; LED_0805
D202: 3V3DC; LED_0805
D203: 5VDC; LED_0805
P201: Mode_Bridge; Pin_Header_Straight_1x03_Pitch2.54mm
R201, R204: 660Ω; R_0805
R202: 0Ω; R_0805
R203: 2k4Ω; R_0805
TP201: TP3V3; Measurement_Point_Round-SMD-Pad_Small
TP202: TP12V; Pin_Header_Straight_1x01; Digikey-PN Value
U201: LF120ABDT-TR; Digikey-PN 497-8330-1-ND
U202: TPS70933; TPS70933DBVR; Digikey-PN 296-35483-1-ND

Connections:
/PIR13/U+: C202.1, C203.1, R202.2, R203.1, TP202.1, U201.2 (Vout), U202.1 (Vin); also elsewhere on the board
/PIR13/Ub+: P201.2; also elsewhere on the board
/Power System/5V: P201.1, R201.2; also elsewhere on the board
/Power System/U+In: C201.1, U201.1 (Vin); also elsewhere on the board
GND: C201.2, C202.2, C203.2, C204.2, D201.1 (K), D202.1 (K), D203.1 (K), U201.3 (GND), U202.2 (GND); also elsewhere on the board
unnamed: C204.1, P201.3, R204.1, TP201.1, U202.5 (Vout)
unnamed: D201.2 (A), R203.2
unnamed: D202.2 (A), R204.2
unnamed: D203.2 (A), R201.1
unnamed: R202.1, U202.3 (EN)

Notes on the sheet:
Double check the output of the 3.3V and watch out for the voltage drop on the Schottky.

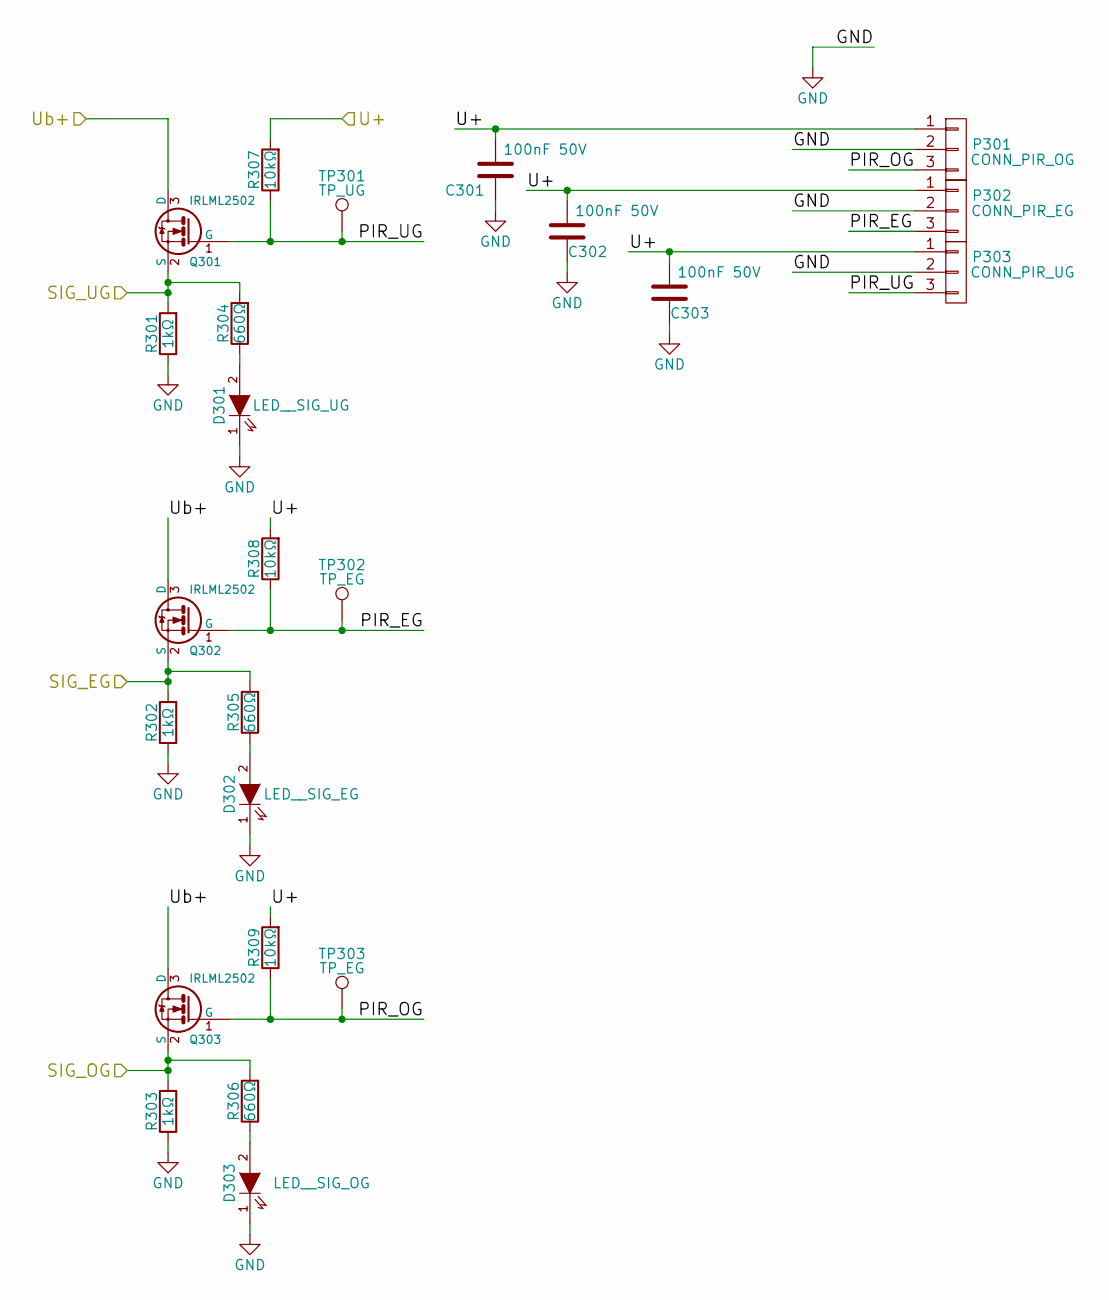
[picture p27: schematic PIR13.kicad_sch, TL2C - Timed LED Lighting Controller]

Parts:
C301, C302, C303: 100nF 50V; C_0805
D301: LED__SIG_UG; LED_0805
D302: LED__SIG_EG; LED_0805
D303: LED__SIG_OG; LED_0805
P301: CONN_PIR_OG; Spring_Terminal_Block_1_x_3; Digikey-PN Value
P302: CONN_PIR_EG; Spring_Terminal_Block_1_x_3; Digikey-PN Value
P303: CONN_PIR_UG; Spring_Terminal_Block_1_x_3; Digikey-PN Value
Q301, Q302, Q303: IRLML2502; SOT-23; Digikey-PN IRLML2502GTRPBFCT-ND
R301, R302, R303: 1kΩ; R_0805
R304, R305, R306: 660Ω; R_0805
R307, R308, R309: 10kΩ; R_0805
TP301: TP_UG; Measurement_Point_Round-SMD-Pad_Small
TP302, TP303: TP_EG; Measurement_Point_Round-SMD-Pad_Small

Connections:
/PIR13/PIR_EG: P302.3, Q302.1 (G), R308.1, TP302.1
/PIR13/PIR_OG: P301.3, Q303.1 (G), R309.1, TP303.1
/PIR13/PIR_UG: P303.3, Q301.1 (G), R307.1, TP301.1
/PIR13/SIG_EG: Q302.2 (S), R302.2, R305.2; also elsewhere on the board
/PIR13/SIG_OG: Q303.2 (S), R303.2, R306.2; also elsewhere on the board
/PIR13/SIG_UG: Q301.2 (S), R301.2, R304.2; also elsewhere on the board
/PIR13/U+: C301.2, C302.2, C303.2, P301.1, P302.1, P303.1, R307.2, R308.2, R309.2; also elsewhere on the board
/PIR13/Ub+: Q301.3 (D), Q302.3 (D), Q303.3 (D); also elsewhere on the board
GND: C301.1, C302.1, C303.1, D301.1 (K), D302.1 (K), D303.1 (K), P301.2, P302.2, P303.2, R301.1, R302.1, R303.1; also elsewhere on the board
unnamed: D301.2 (A), R304.1
unnamed: D302.2 (A), R305.1
unnamed: D303.2 (A), R306.1

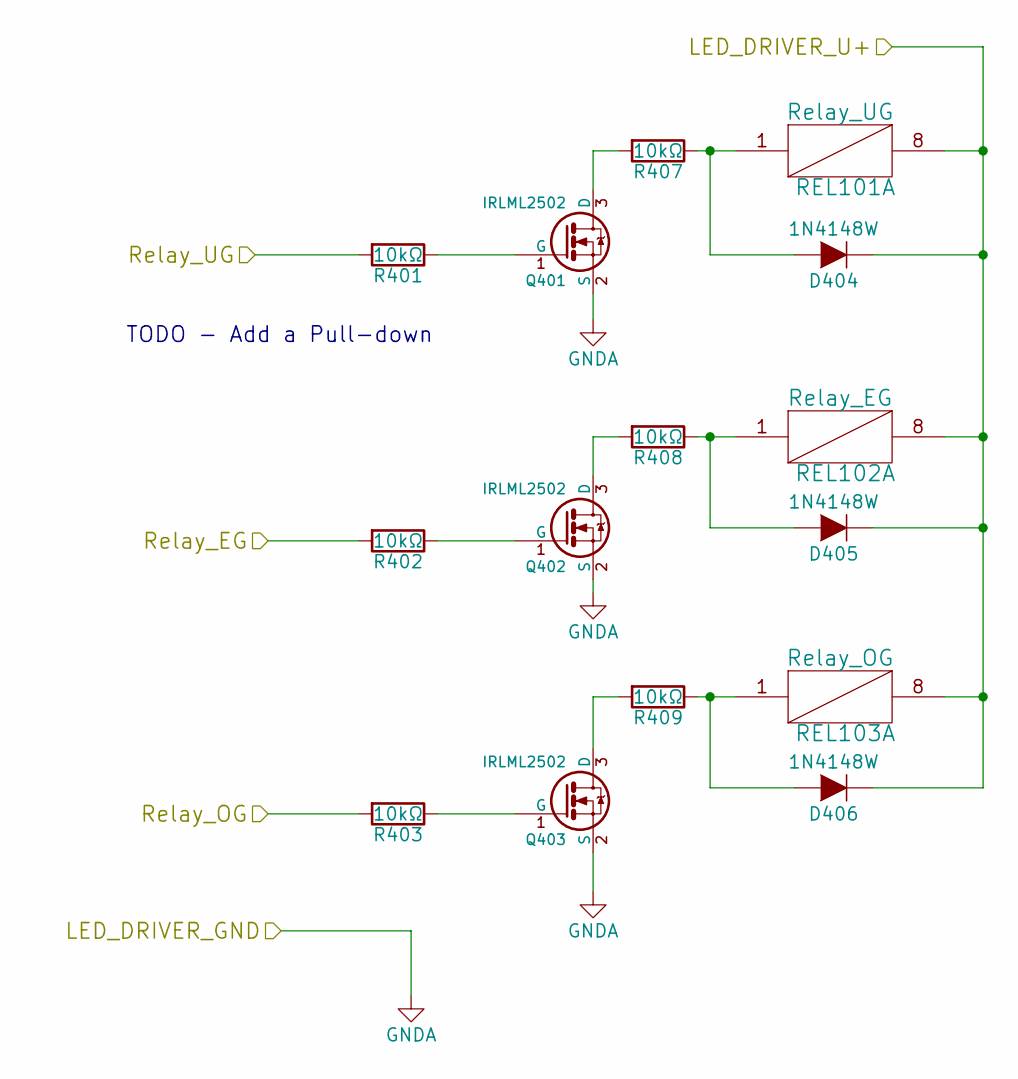
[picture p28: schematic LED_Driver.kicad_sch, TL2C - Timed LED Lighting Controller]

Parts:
D404, D405, D406: 1N4148W; SOD-123; Digikey-PN 1N4148W-E3-18CT-ND
Q401: IRLML2502; SOT-23; Digikey-PN IRLML2502GTRPBFCT-ND
Q402, Q403: IRLML2502; SOT-23; Digikey-PN RLML2502GTRPBFCT-ND
R401, R402, R403, R407, R408, R409: 10kΩ; R_0805
REL101: Relay_UG; JW1AFSN-12-F; Digikey-PN N/A
REL102: Relay_EG; JW1AFSN-12-F; Digikey-PN N/A
REL103: Relay_OG; JW1AFSN-12-F; Digikey-PN N/A

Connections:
/LED Driver/LED_DRIVER_U+: D404.1 (K), D405.1 (K), D406.1 (K), REL101.8, REL102.8, REL103.8; also elsewhere on the board
/LED Driver/Relay_EG: R402.2; also elsewhere on the board
/LED Driver/Relay_OG: R403.2; also elsewhere on the board
/LED Driver/Relay_UG: R401.2; also elsewhere on the board
GNDA: Q401.2 (S), Q402.2 (S), Q403.2 (S); also elsewhere on the board
unnamed: D404.2 (A), R407.1, REL101.1
unnamed: D405.2 (A), R408.1, REL102.1
unnamed: D406.2 (A), R409.1, REL103.1
unnamed: Q401.1 (G), R401.1
unnamed: Q401.3 (D), R407.2
unnamed: Q402.1 (G), R402.1
unnamed: Q402.3 (D), R408.2
unnamed: Q403.1 (G), R403.1
unnamed: Q403.3 (D), R409.2

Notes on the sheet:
TODO - Add a Pull-down

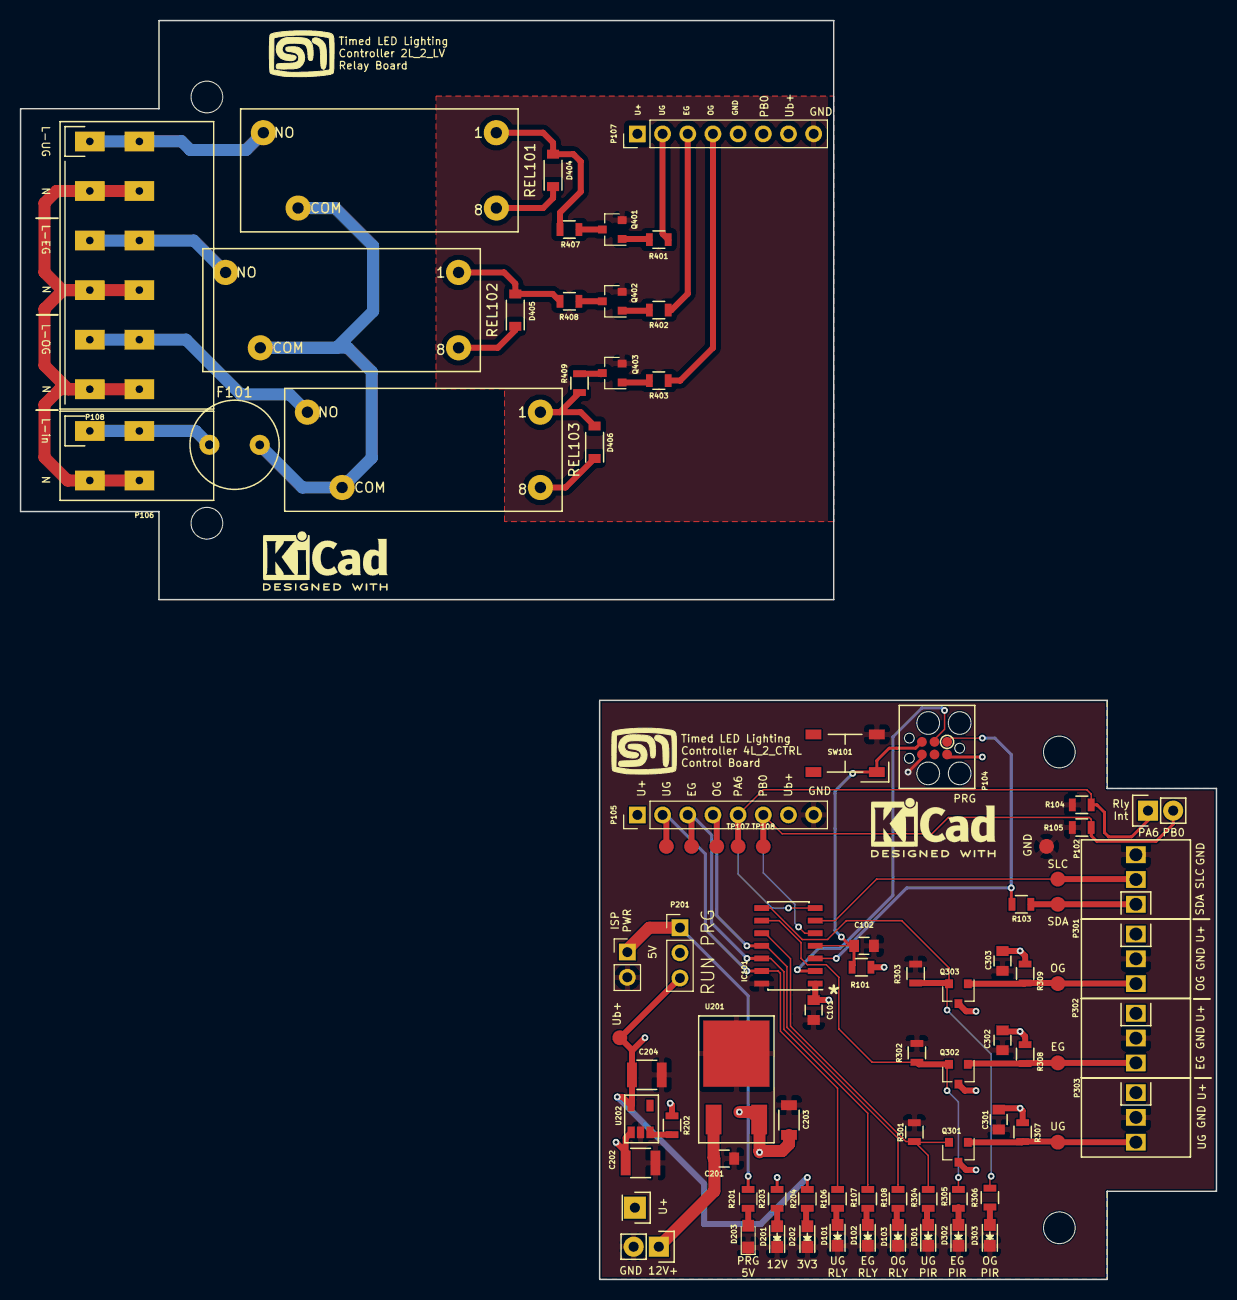
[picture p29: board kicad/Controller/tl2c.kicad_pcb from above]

Board: 4 copper layers, 120.7 x 127.0 mm, 87 parts (0 on the bottom side), 52 nets.

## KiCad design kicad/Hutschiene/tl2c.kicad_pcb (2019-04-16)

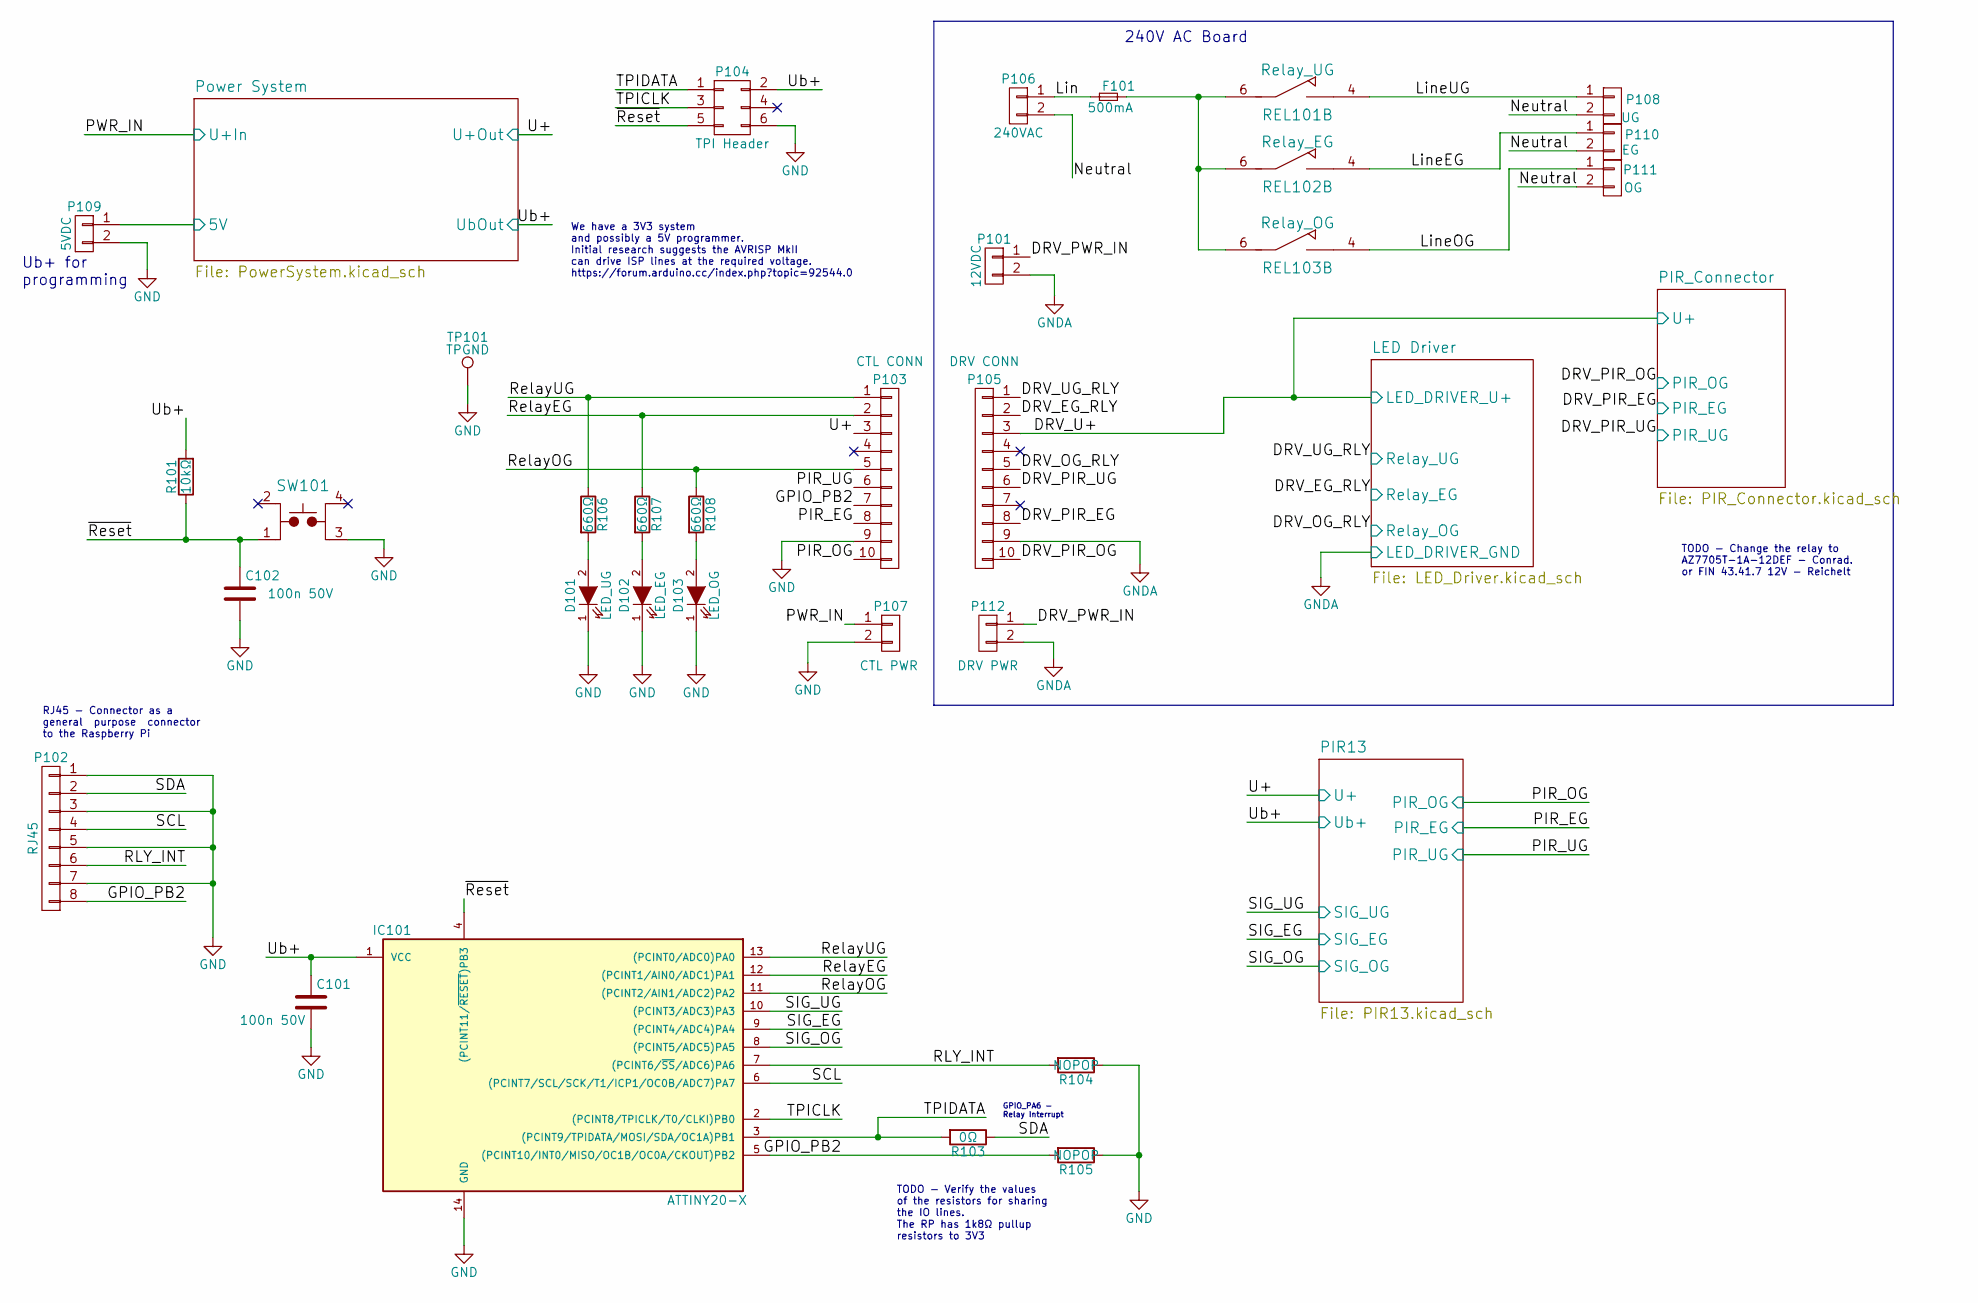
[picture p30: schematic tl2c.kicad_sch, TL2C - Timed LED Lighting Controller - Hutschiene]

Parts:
C101, C102: 100n 50V; C_0805
D101: LED_UG; LED_0805_HandSoldering
D102: LED_EG; LED_0805_HandSoldering
D103: LED_OG; LED_0805_HandSoldering
F101: 500mA; Fuse_TE5_Littlefuse-ESKA_887_O14; Digikey-PN Value
IC101: ATTINY20-X; SOIC-14_3.9x8.7mm_Pitch1.27mm; Digikey-PN ATTINY20-SSURCT-ND
P101: 12VDC; PCB_Screw_Terminal_Block_5.08mm_x_2; Digikey-PN Value
P102: RJ45; RJ45_8P8C
P103: CTL CONN; Pin_Header_Straight_2x05_Pitch2.54mm
P104: TPI Header; Tag-Connect_TC2030-IDC-NL; Digikey-PN Value
P105: DRV CONN; Socket_Strip_Straight_2x05_Pitch2.54mm
P106: 240VAC; PCB_Screw_Terminal_Block_5.08mm_x_2; Digikey-PN Value
P107: CTL PWR; Pin_Header_Straight_1x02_Pitch2.54mm
P108: UG; PCB_Screw_Terminal_Block_5.08mm_x_2; Digikey-PN Value
P109: 5VDC; Pin_Header_Straight_1x02_Pitch2.54mm; Digikey-PN Value
P110: EG; PCB_Screw_Terminal_Block_5.08mm_x_2; Digikey-PN Value
P111: OG; PCB_Screw_Terminal_Block_5.08mm_x_2; Digikey-PN Value
P112: DRV PWR; Pin_Header_Straight_1x02_Pitch2.54mm
R101: 10kΩ; R_0805
R103: 0Ω; R_0805
R104, R105: NOPOP; R_0805
R106, R107, R108: 660Ω; R_0805_HandSoldering
REL101: Relay_UG; JW1AFSN-12-F; Digikey-PN Value
REL102: Relay_EG; JW1AFSN-12-F; Digikey-PN Value
REL103: Relay_OG; JW1AFSN-12-F; Digikey-PN Value
SW101: TL3315NF160Q; TACTILE_FSM2JSMAA; Digikey-PN Value
TP101: TPGND; Measurement_Point_Round-SMD-Pad_Small

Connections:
/DRV_PWR_IN: P101.1, P112.1
/GPIO_PB2: IC101.5 ((PCINT10/INT0/MISO/OC1B/OC0A/CKOUT)PB2), P102.8, P103.7, R105.2
/LED Driver/LED_DRIVER_U+: P105.3; also elsewhere on the board
/LED Driver/Relay_EG: P105.2; also elsewhere on the board
/LED Driver/Relay_OG: P105.5; also elsewhere on the board
/LED Driver/Relay_UG: P105.1; also elsewhere on the board
/Lin: F101.1, P106.1
/LineEG: P110.1, REL102.4
/LineOG: P111.1, REL103.4
/LineUG: P108.1, REL101.4
/Neutral: P106.2, P108.2, P110.2, P111.2
/PIR13/PIR_EG: P103.8; also elsewhere on the board
/PIR13/PIR_OG: P103.10; also elsewhere on the board
/PIR13/PIR_UG: P103.6; also elsewhere on the board
/PIR13/SIG_EG: IC101.9 ((PCINT4/ADC4)PA4); also elsewhere on the board
/PIR13/SIG_OG: IC101.8 ((PCINT5/ADC5)PA5); also elsewhere on the board
/PIR13/SIG_UG: IC101.10 ((PCINT3/ADC3)PA3); also elsewhere on the board
/PIR13/U+: P103.3; also elsewhere on the board
/PIR13/Ub+: C101.1, IC101.1 (VCC), P104.2, R101.2; also elsewhere on the board
/PIR_Connector/PIR_EG: P105.8; also elsewhere on the board
/PIR_Connector/PIR_OG: P105.10; also elsewhere on the board
/PIR_Connector/PIR_UG: P105.6; also elsewhere on the board
/Power System/5V: P109.1; also elsewhere on the board
/Power System/U+In: P107.1; also elsewhere on the board
/RLY_INT: IC101.7 ((PCINT6/~SS/ADC6)PA6), P102.6, R104.2
/RelayEG: IC101.12 ((PCINT1/AIN0/ADC1)PA1), P103.2, R107.1
/RelayOG: IC101.11 ((PCINT2/AIN1/ADC2)PA2), P103.5, R108.1
/RelayUG: IC101.13 ((PCINT0/ADC0)PA0), P103.1, R106.1
/SCL: IC101.6 ((PCINT7/SCL/SCK/T1/ICP1/OC0B/ADC7)PA7), P102.4
/SDA: P102.2, R103.1
/TPICLK: IC101.2 ((PCINT8/TPICLK/T0/CLKI)PB0), P104.3
/TPIDATA: IC101.3 ((PCINT9/TPIDATA/MOSI/SDA/OC1A)PB1), P104.1, R103.2
/~Reset: C102.1, IC101.4 ((PCINT11/~RESET)PB3), P104.5, R101.1, SW101.1
GND: C101.2, C102.2, D101.1 (K), D102.1 (K), D103.1 (K), IC101.14 (GND), P102.1, P102.3, P102.5, P102.7, P103.9, P104.6, P107.2, P109.2, R104.1, R105.1, SW101.3, TP101.1; also elsewhere on the board
GNDA: P101.2, P105.9, P112.2; also elsewhere on the board
unnamed: D101.2 (A), R106.2
unnamed: D102.2 (A), R107.2
unnamed: D103.2 (A), R108.2
unnamed: F101.2, REL101.6, REL102.6, REL103.6

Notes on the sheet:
We have a 3V3 system and possibly a 5V programmer. Initial research suggests the AVRISP MkII can drive ISP lines at the required voltage. https://forum.arduino.cc/index.php?topic=92544.0
Ub+ for programming
240V AC Board
GPIO_PA6 - Relay Interrupt
TODO - Change the relay to AZ7705T-1A-12DEF - Conrad. or FIN 43.41.7 12V - Reichelt
TODO - Verify the values of the resistors for sharing the IO lines.
RJ45 - Connector as a general purpose connector to the Raspberry Pi
The RP has 1k8Ω pullup resistors to 3V3


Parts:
C201: 0.1μF 50V; C_0805
C202: 1μF 25V; C_0805; Digikey-PN Value
C203: 2.2μF 50V; C_0805; Digikey-PN N/A
C204: 2.2μF 16V; C_0805; Digikey-PN Value
D202: 3V3DC; LED_0805_HandSoldering
P201: Mode_Bridge; Pin_Header_Straight_1x03_Pitch2.54mm
R202: 0Ω; R_0805
R204: 660Ω; R_0805_HandSoldering
U201: LF120ABDT-TR; Digikey-PN 497-8330-1-ND
U202: TPS70933; TPS70933DBVR; Digikey-PN 296-35483-1-ND

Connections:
/PIR13/U+: C202.1, C203.1, R202.2, U201.2 (Vout), U202.1 (Vin); also elsewhere on the board
/PIR13/Ub+: P201.2; also elsewhere on the board
/Power System/5V: P201.1; also elsewhere on the board
/Power System/U+In: C201.1, U201.1 (Vin); also elsewhere on the board
GND: C201.2, C202.2, C203.2, C204.2, D202.1 (K), U201.3 (GND), U202.2 (GND); also elsewhere on the board
unnamed: C204.1, P201.3, R204.1, U202.5 (Vout)
unnamed: D202.2 (A), R204.2
unnamed: R202.1, U202.3 (EN)

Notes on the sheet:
Double check the output of the 3.3V and watch out for the voltage drop on the Schottky.


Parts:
Q301, Q302, Q303: IRLML2502; SOT-23; Digikey-PN IRLML2502GTRPBFCT-ND
R301, R302, R303: 1kΩ; R_0805
R307, R308, R309: 10kΩ; R_0805

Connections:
/PIR13/PIR_EG: Q302.1 (G), R308.1; also elsewhere on the board
/PIR13/PIR_OG: Q303.1 (G), R309.1; also elsewhere on the board
/PIR13/PIR_UG: Q301.1 (G), R307.1; also elsewhere on the board
/PIR13/SIG_EG: Q302.2 (S), R302.2; also elsewhere on the board
/PIR13/SIG_OG: Q303.2 (S), R303.2; also elsewhere on the board
/PIR13/SIG_UG: Q301.2 (S), R301.2; also elsewhere on the board
/PIR13/U+: R307.2, R308.2, R309.2; also elsewhere on the board
/PIR13/Ub+: Q301.3 (D), Q302.3 (D), Q303.3 (D); also elsewhere on the board
GND: R301.1, R302.1, R303.1; also elsewhere on the board


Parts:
D404, D405, D406: 1N4148W; SOD-123; Digikey-PN 1N4148W-E3-18CT-ND
Q401: IRLML2502; SOT-23; Digikey-PN IRLML2502GTRPBFCT-ND
Q402, Q403: IRLML2502; SOT-23; Digikey-PN RLML2502GTRPBFCT-ND
R401, R402, R403, R407, R408, R409: 0kΩ; R_0805
R404, R405, R406: 10kΩ; R_0805
REL101: Relay_UG; JW1AFSN-12-F; Digikey-PN N/A
REL102: Relay_EG; JW1AFSN-12-F; Digikey-PN N/A
REL103: Relay_OG; JW1AFSN-12-F; Digikey-PN N/A

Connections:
/LED Driver/LED_DRIVER_U+: D404.1 (K), D405.1 (K), D406.1 (K), REL101.8, REL102.8, REL103.8; also elsewhere on the board
/LED Driver/Relay_EG: R402.2, R405.2; also elsewhere on the board
/LED Driver/Relay_OG: R403.2, R406.2; also elsewhere on the board
/LED Driver/Relay_UG: R401.2, R404.2; also elsewhere on the board
GNDA: Q401.2 (S), Q402.2 (S), Q403.2 (S), R404.1, R405.1, R406.1; also elsewhere on the board
unnamed: D404.2 (A), R407.1, REL101.1
unnamed: D405.2 (A), R408.1, REL102.1
unnamed: D406.2 (A), R409.1, REL103.1
unnamed: Q401.1 (G), R401.1
unnamed: Q401.3 (D), R407.2
unnamed: Q402.1 (G), R402.1
unnamed: Q402.3 (D), R408.2
unnamed: Q403.1 (G), R403.1
unnamed: Q403.3 (D), R409.2


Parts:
C501, C502, C503: 100nF 50V; C_0805_HandSoldering; MPN Value
P501: CONN_PIR_OG; PCB_Screw_Terminal_Block_5.8mm_x_3
P502: CONN_PIR_EG; PCB_Screw_Terminal_Block_5.8mm_x_3
P503: CONN_PIR_UG; PCB_Screw_Terminal_Block_5.8mm_x_3

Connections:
/LED Driver/LED_DRIVER_U+: C501.1, C502.1, C503.1, P501.1, P502.1, P503.1; also elsewhere on the board
/PIR_Connector/PIR_EG: P502.3; also elsewhere on the board
/PIR_Connector/PIR_OG: P501.3; also elsewhere on the board
/PIR_Connector/PIR_UG: P503.3; also elsewhere on the board
GNDA: C501.2, C502.2, C503.2, P501.2, P502.2, P503.2; also elsewhere on the board



Board: 4 copper layers, 175.9 x 86.5 mm, 71 parts (30 on the bottom side), 51 nets.

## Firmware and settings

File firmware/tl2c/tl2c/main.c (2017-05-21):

/*
 * tl2c.c
 *
 * Created: 18/02/2017 15:26:52
 * Author : Steve
 */ 

#include <avr/io.h>
#include <avr/interrupt.h>
#include "common.h"
#include "TWI_slave.h"


// volatile unsigned char TL2C_pir_interrupt;
volatile unsigned char timer_delay = 0;
volatile union TL2C_status_reg_t TL2C_pir_state;
unsigned char interrupt_flag;

int main(void)
{
    /* Replace with your application code */

	// Outputs
	// PA0 - UG Untergeschoss relay
	// PA1 - EG	Erdgeschoss relay
	// PA2 - OG	Obergeschoss relay

	// Inputs 
	// PA3 - UG Untergeschoss PIR signal
	// PA4 - EG Erdgeschoss PIR signal
	// PA5 - OG Obergeschoss PIR signal

	// Interrupt (Driver)
	// PA6 - General purpose interrupt output


#define CTC1_MODE	// Testing the timers and interrupts

// The the data direction for the relay outputs
DDRA = 0;
DDRA |= ( 1 << PORTA0 ) | ( 1 << PORTA1 ) | ( 1 << PORTA2 ) | (1 << PORTA6);
PUEA = 0;
PUEA |= ( 1 << PUEA5) | ( 1 << PUEA4) | ( 1 << PUEA3);
// Set the Pin Change interrupts for
PCMSK0 |=   (1<<PCINT5)| (1<<PCINT4)| (1<<PCINT3); // 0b00111000;
GIMSK |= ( 1<<PCIE0 );

#ifdef CTC1_MODE
	// This is the CTC mode whereby the counter registers are are set and a
	// Wave Generator is created. In this example only the OCR0A is used, It
	// is possible also to configure the OCR0B as well.
	// unsigned int startValue = 0x03D0;
	TCCR1A  = 0;										// Reset the operation
	TCCR1B  |=  ( 1 << WGM12 );							// CTC operation
	TCCR1B  |=  ( 5 << CS10  );							// 1024 Pre-scaler
	OCR1AH = 0x03;										// Set the start value - ~0.5Hz
	OCR1AL = 0xD0;										// 16 bit register ... write the high byte first!
	TIMSK |= ( 1 << OCIE1A );							// Enable the interrupt on OCR0A
#endif


#ifdef CTC_MODE
	// This is the CTC mode whereby the counter registers are are set and a
	// Wave Generator is created. In this example only the OCR0A is used, It
	// is possible also to configure the OCR0B as well.
	TCCR0A  = 0;										// Reset the operation
	TCCR0A  |=  ( 1 << WGM01 );							// CTC operation
	TCCR0B  |=  ( 5 << CS00  );							// 1024 Pre-scaler
	OCR0A = 0xF4;									// Set the start value
	TIMSK |= ( 1 << OCIE0A );							// Enable the interrupt on OCR0A
#endif

#ifdef NORMAL_MODE
	// In normal mode, only the TCNT0 needs to be set ( as well as the pre-scaler).
	unsigned int startValue = 0xFF;
	TCCR0A  = 0;										// Reset the operation
	TCCR0B  |=  ( 5 << CS00  );							// 1024 Pre-scaler
	TCNT0  = startValue;								// Set the start value
	TIMSK |= ( 1 << TOIE0 );							// Enable the over flow interrupt
#endif

	PORTA &= ~( 7 << PORTA0 );	// Turn off ALL indicator LEDs.
	led_flag = 0;
	TL2C_Relay_ctl.relay_state.TL2C_INT = 0;
	// TL2C_pir_interrupt = 0;
	TL2C_Registers.TL2C_status_reg.TL2C_PINT = 0;
	TWI_Slave_Initialise( 0x40 );

	TL2C_Relay_ctl.relay1_counter = TL2C_Registers.TL2C_Zone1_On_Delay;
	TL2C_Relay_ctl.relay2_counter = TL2C_Registers.TL2C_Zone2_On_Delay;
	TL2C_Relay_ctl.relay3_counter = TL2C_Registers.TL2C_Zone3_On_Delay;

	sei();

    TWI_Start();
    while (1) 
    {
		// if( TL2C_pir_interrupt ){
		if( TL2C_Registers.TL2C_status_reg.TL2C_PINT ){
			// Here we are confident that there has been a pin change. We have not
			// clarified exactly which pin has changed.

			// If the Zone activate bit is set OR the associated bit in the 
			// status register, then consider this as ON.
			if(TL2C_Registers.TL2C_config_reg.TL2C_Z1A || TL2C_pir_state.TL2C_Z1F ){	// UG - Zone 1
			    TL2C_pir_state.TL2C_Z1F = 0;
			    TL2C_Registers.TL2C_status_reg.TL2C_Z1F = 1;
				TL2C_Relay_ctl.relay_state.TL2C_RLY_UG = 1;
				TL2C_Registers.TL2C_status_reg.TL2C_RINT = 1;
				TL2C_Relay_ctl.relay1_counter = TL2C_Registers.TL2C_Zone1_On_Delay;
			}
			if(TL2C_Registers.TL2C_config_reg.TL2C_Z2A || TL2C_pir_state.TL2C_Z2F){	// EG - Zone 2
			    TL2C_pir_state.TL2C_Z2F = 0;
			    TL2C_Registers.TL2C_status_reg.TL2C_Z2F = 1;
				TL2C_Relay_ctl.relay_state.TL2C_RLY_EG = 1;
				TL2C_Registers.TL2C_status_reg.TL2C_RINT = 1;
				TL2C_Relay_ctl.relay2_counter = TL2C_Registers.TL2C_Zone2_On_Delay;
			}
			if(TL2C_Registers.TL2C_config_reg.TL2C_Z3A || TL2C_pir_state.TL2C_Z3F){	// OG - Zone 3
			    TL2C_pir_state.TL2C_Z3F = 0;
			    TL2C_Registers.TL2C_status_reg.TL2C_Z3F = 1;
				TL2C_Relay_ctl.relay_state.TL2C_RLY_OG = 1;
				TL2C_Registers.TL2C_status_reg.TL2C_RINT = 1;
				TL2C_Relay_ctl.relay3_counter = TL2C_Registers.TL2C_Zone3_On_Delay;
			}
			// TL2C_pir_interrupt = 0;
			TL2C_Registers.TL2C_status_reg.TL2C_PINT = 0;

			// Raise the Interrupt back to the Master
			// TL2C_Registers.TL2C_status_reg.TL2C_RINT = ((TL2C_Relay_ctl.relay_state.TL2C_INT == 0) && (TL2C_Relay_ctl.relay_state.all & 0b00000111));
// 			if (TL2C_Relay_ctl.relay_state.all & 0b00000111) {
// 				TL2C_Registers.TL2C_status_reg.TL2C_RINT = 1;
// 				// TL2C_Relay_ctl.relay_state.TL2C_INT = 1;
// 			}
		}

		// Every pulse cycle...
		if( led_flag){	// The heart beat is used to keep the time for the system.	

			// If the relay is set, then count down.
			if((!TL2C_Registers.TL2C_config_reg.TL2C_Z1A) && TL2C_Relay_ctl.relay_state.TL2C_RLY_UG){
				TL2C_Relay_ctl.relay1_counter--;
				if( !TL2C_Relay_ctl.relay1_counter ){
					TL2C_Relay_ctl.relay_state.TL2C_RLY_UG =  0;
					TL2C_Registers.TL2C_status_reg.TL2C_Z1F = 0;
					TL2C_Registers.TL2C_status_reg.TL2C_RINT = 1;
					TL2C_Relay_ctl.relay1_counter = TL2C_Registers.TL2C_Zone1_On_Delay;
				}
			}

			if((!TL2C_Registers.TL2C_config_reg.TL2C_Z2A) && TL2C_Relay_ctl.relay_state.TL2C_RLY_EG){
				TL2C_Relay_ctl.relay2_counter--;
				if( !TL2C_Relay_ctl.relay2_counter ){
					TL2C_Relay_ctl.relay_state.TL2C_RLY_EG = 0;
					TL2C_Registers.TL2C_status_reg.TL2C_Z2F = 0;
					TL2C_Registers.TL2C_status_reg.TL2C_RINT = 1;
					TL2C_Relay_ctl.relay2_counter = TL2C_Registers.TL2C_Zone2_On_Delay;
				}
			}

			if((!TL2C_Registers.TL2C_config_reg.TL2C_Z3A) && TL2C_Relay_ctl.relay_state.TL2C_RLY_OG){
				TL2C_Relay_ctl.relay3_counter--;
				if( !TL2C_Relay_ctl.relay3_counter ){
					TL2C_Relay_ctl.relay_state.TL2C_RLY_OG = 0;
					TL2C_Registers.TL2C_status_reg.TL2C_Z3F = 0;
					TL2C_Registers.TL2C_status_reg.TL2C_RINT = 1;
					TL2C_Relay_ctl.relay3_counter = TL2C_Registers.TL2C_Zone3_On_Delay;
				}
			}
			
			unsigned char state = PORTA & 0b10111000;
			if( interrupt_flag == 0 && TL2C_Registers.TL2C_status_reg.TL2C_RINT) {
				// Reset the interrupt on the next cycle.
				interrupt_flag = 1;
			} else {
				TL2C_Registers.TL2C_status_reg.TL2C_RINT = 0;
				interrupt_flag = 0;
			}
			TL2C_Relay_ctl.relay_state.TL2C_INT = TL2C_Registers.TL2C_status_reg.TL2C_RINT;
			PORTA = state | TL2C_Relay_ctl.relay_state.all;

// 			if( (led_flag >> red_LED)&1 ){
// 			   PORTA ^= (1 << PORTA0);
// 			}
// 			if( (led_flag >> yellow_LED)&1 ){
// 			   PORTA ^= (1 << PORTA1);
// 			}
// 			if( (led_flag >> green_LED) & 1 ){
// 			   PORTA ^= (1 << PORTA2);
// 			}

			led_flag = 0;
		}
    }
}


ISR(PCINT0_vect){
	// unsigned char enabled = (3>>(TL2C_Registers.TL2C_config_reg.all & 0b00111000));
	// TL2C_Registers.TL2C_status_reg.all = (PINA >> 3) & (TL2C_Registers.TL2C_config_reg.all & 0b00000111);

	// Shift the three input pins three bits to the right
	// Shift the three enable bits four bits to the right
	// AND the result to ensure that all enabled bits are allowed to be registered.
	// TL2C_Registers.TL2C_status_reg.all = (((PINA >> 3) ^ 0xFF) & (TL2C_Registers.TL2C_config_reg.all >> 4));
	TL2C_pir_state.all = (((PINA >> 3) ^ 0xFF) & (TL2C_Registers.TL2C_config_reg.all >> 4));
	TL2C_Registers.TL2C_status_reg.TL2C_PINT = 1;
	// TL2C_pir_interrupt = 1;
}

#ifdef CTC1_MODE
ISR(TIM1_COMPA_vect) {
	// OCR0A = startValue;	// This value does not have to be reset like in Normal Mode.
	led_flag |= (1 << red_LED);
	
}
#endif

#ifdef CTC_MODE
ISR(TIM0_COMPA_vect) {
	// OCR0A = startValue;	// This value does not have to be reset like in Normal Mode.
	// led_flag |= (1 << green_LED);
	// led_flag |= (1 << red_LED);
	timer_delay++;
	if(timer_delay > 3 ){
		led_flag |= (1 << red_LED);
		timer_delay = 0;
	}
	
}
#endif

#ifdef NORMAL_MODE
ISR(TIM0_OVF_vect) {
	TCNT0  = startValue;	// This value must be reset each time to keep the frequency
	//led_flag |= (1 << red_LED);
}
#endif

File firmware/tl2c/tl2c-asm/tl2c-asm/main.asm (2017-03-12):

;
; tl2c-asm.asm
;
; Created: 24/02/2017 18:00:31
; Author : Steve Mayze
;


; The inc file is located in
; C:\Program Files (x86)\Atmel\Studio\packs\atmel\ATtiny_DFP\1.1.102\avrasm\inc
.INCLUDE "tn20def.inc"

.EQU TL2C_default_slave_address = 0x40
.EQU TL2C_default_delay = 10	;	The default delay to place into the configuration registers.

.EQU red_LED = 0x01
.EQU yellow_LED = 0x02
.EQU green_LED = 0x4

.EQU TL2C_Z1F = 0		; TL2C Zone 1 status flag
.EQU TL2C_Z2F = 1		; TL2C Zone 2 status flag
.EQU TL2C_Z3F = 2		; TL2C Zone 3 status flag

.EQU TL2C_Z1A = 0		; TL2C Zone 1 Activation flag
.EQU TL2C_Z2A = 1		; TL2C Zone 2 Activation flag
.EQU TL2C_Z3A = 2		; TL2C Zone 3 Activation flag

.EQU TL2C_PIR1E = 4		; TL2C Zone 1 PIR13 Enable Flag
.EQU TL2C_PIR2E = 5		; TL2C Zone 2 PIR13 Enable flag
.EQU TL2C_PIR3E = 6		; TL2C Zone 3 PIR13 Enable flag



.EQU TWI_IDLE = 0
.EQU TWI_ADDRESS_RECEIVED = 1
.EQU TWI_REGISTER_ADDRESS = 2
.EQU TWI_MASTER_WRITE = 3
.EQU TWI_MASTER_READ = 4


.ORG 0
	rjmp reset

.ORG OC0Aaddr
	rjmp isr_tov

.ORG TWIaddr
	rjmp isr_TWI_Handler

.DSEG
led_flag:	.BYTE 1			; Flag for the timer overlfow to toggle the LED
TWI_State: .BYTE 1

TL2C_STATUS: .BYTE 1			;	TL2C Status Register
TL2C_CONFIG: .BYTE 1			;	TL2C Configuration Register
TL2C_Z1ON: .BYTE 1			;	TL2C Zone 1 ON Delay - Minutes
TL2C_Z2ON: .BYTE 1			;	TL2C Zone 2 ON Delay - Minutes
TL2C_Z3ON: .BYTE 1			;	TL2C Zone 3 ON Delay - Minutes
TL2C_ADDRESS: .BYTE 1		;	TL2C I2C COnfigurable Address


.CSEG
.ORG INT_VECTORS_SIZE

// ===========================================================================
// Cold Start
reset:

; Initialise the IO
	ldi r16, 1<<PORTA0 | 1<<PORTA1 | 1<<PORTA2	; Enable PORTA[0:2] as output
	out DDRA, r16								; Set the Direction for PORTA[0:2] to output

; Initialise the TIMER0 to interrupt on CTC0
	ldi r16, 1<<WGM01							; Set the wave generator to CTC
	out TCCR0A, r16
	ldi r16, 0x05<<CS00							; 1024 Pre-scaler
    out TCCR0B, r16
	ldi r16, 0xFF								; Set the start value
	out OCR0A, r16
	ldi r16, 1<<TOV0							; Clear pending interrupts/
	out TIFR, r16
	ldi r16, 1<<OCIE0A							; Enable the interrupt on OCR0A (CTC 0 overflow)
	out TIMSK, r16

	ldi r16, 0x00								; initialise the toggle flag
	sts led_flag, r16							; Using a byte instead of keeping it all in the registers
												; to show-case the use of .BYTE.

; Initialise the TL2C
	ldi r16, 0x00								; Set the status register to all OFF
	sts TL2C_STATUS, r16
	ldi r16, 1<<TL2C_PIR1E | 1<<TL2C_PIR2E		; Enable zones 1 and 2 as a default
	sts TL2C_CONFIG, r16
	ldi r16, TL2C_default_delay					; Set the default delay for each of the zones.
	sts TL2C_Z1ON, r16
	sts TL2C_Z2ON, r16
	sts TL2C_Z3ON, r16
	ldi r16, TL2C_default_slave_address			; Configure the default slave address
	sts TL2C_ADDRESS, r16

// ===========================================================================
// Warm Start
warm_boot:
; Initialise the Two Wire Slave Module
	ldi r16, 0x00								; We are not using the Addressing Mask
	out TWSAM, r16
	lds r16, TL2C_ADDRESS
	ori r16, 1<<TWSA0							; Set the slave address - also set the General call address flg
	out TWSA, r16

	ldi r16, 1<<TWEN							; Enable the Two Wire module - but not the interrupts just yet.
	out TWSCRA, r16

; Enable the global interrupts
	sei											; Enable interrupts

; Finish the configurtation of the Two Wire module
	ldi r16, TWI_IDLE							; Set the state of the TWI as idle i.e. waiting for a START
	sts TWI_State, r16
	ldi r16, 1<<TWASIE | 1<<TWEN | 1<<TWSIE 	; Enable the TWI Address/Stop Interrupt, TWI Interface, TWI Stop Interrupt
	out TWSCRA, r16
	ldi r16, 0									; Reset any commands in the TWI Status Register B
	out TWSCRB, r16

; ============================================================================
;	MAIN Program Body
; ============================================================================
blinky:
	lds r16, led_flag
	cpi r16, 0x00								; If the toggle flag is true, then toggle the LED
	breq blinky

	ldi r17, 0x00								; Reset the LED flag
	sts led_flag, r17

case_red:
	mov r17, r16
	andi r17, red_LED
	cpi r17, 0x00							; Case RED
	breq case_yellow
	rcall toggle_RED

case_yellow:
	mov r17, r16
	andi r17, yellow_LED
	cpi r17, 0x00							; Case YELLOW
	breq case_green
	rcall toggle_YELLOW

case_green:
	mov r17, r16
	andi r17, green_LED
	cpi r17, 0x00							; Case GREEN
	breq default
	rcall toggle_GREEN
default:
	rjmp blinky

// ===========================================================================
// Sub-routines

toggle_RED:
	push r16
	push r17
	ldi r16, red_LED
	in r17, PORTA			; Read the state of PORTA
	eor r17, r16			; Toggle the PORTA with the red_LED
	out PORTA, r17			; Wirte out the result
	pop r17
	pop r16
	ret

toggle_YELLOW:
	push r16
	push r17
	ldi r16, yellow_LED
	in r17, PORTA			; Read the state of PORTA
	eor r17, r16			; Toggle the PORTA with the yellow_LED
	out PORTA, r17			; Wirte out the result
	pop r17
	pop r16
	ret

toggle_GREEN:
	push r16
	push r17
	ldi r16, green_LED
	in r17, PORTA			; Read the state of PORTA
	eor r17, r16			; Toggle the PORTA with the green_LED
	out PORTA, r17			; Wirte out the result
	pop r17
	pop r16
	ret

// ===========================================================================
// Interrupt service routine for handling the CTC0 overflow
isr_tov:
	; Save off any registers that could be used elsewhere here.
	push r18
	push r19

	ldi r19, red_LED		; Set the RED LED, but don't destroy any other possible flags.
	lds r18, led_flag
	or r18, r19
	sts led_flag, r18

	pop r19
	pop r18
	reti


// ===========================================================================
// Interrupt service routine for handling the TWI interrupt
isr_TWI_Handler:
	; The interrupt will be one of either ADRESS, STOP or DATA.
	; The intial state will be waiting for a START i.e. ADRESS. This is not
	; a good assumption, but it is a place to start.

	; Save off any registers that could be used elsewhere here.
	push r18
	push r19
	push r20

	; What was the cause of the interrupt? Is this ADDRESS, STOP or DATA?
	in r18, TWSSRA
	sbrs r18, TWASIF						; 1 = ADDRESS or STOP
	rjmp data_received
	sbrs r18, TWAS 							; 1 = Address Interrupt
	rjmp stop_detected						; Just reset the flags and wait for the next.

address_detected:
	; send back the ACK and prepare to send or receive
	ldi r19, 0<<TWAA | 1<<TWCMD1 | 1<<TWCMD0	; 0=TWAA: ACK, 11=TWCMD
	out TWSCRB, r19
	sbrc r18, TWDIR							; Test the READ/WRITE bit
	rjmp master_read
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

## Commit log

2016-12-10 Initial checkin of the project structure
    [tl2c.kicad_pcb, tl2c.sch]
2016-12-10 Started the schematic
    [tl2c.sch]
2016-12-10 Completed the initial schematic
    [tl2c.sch]
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2016-12-14 Changes to the schematic after a review - added further test points and LEDs
    [LED_Driver.sch, PIR13.sch, PowerSystem.sch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]
2016-12-16 Started assigning foot prints to the parts
    [LED_Driver.sch, PIR13.sch, PowerSystem.sch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]
2016-12-17 Added more footprints to the parts
    [LED_Driver.sch, PowerSystem.sch, tl2c.sch]
2016-12-17 Provided a place holder connector for the 240V side and started the layout
    [tl2c.kicad_pcb, tl2c.sch]
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2016-12-18 Started adding tracks to the layout
    [LED_Driver.sch, PIR13.sch, PowerSystem.sch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]
2016-12-18 Retried the track layouts for the contoller part.
    [tl2c.kicad_pcb]
2016-12-20 Completed the first draft of the board - moved to 4 layers
    [tl2c.kicad_pcb]
2016-12-23 A change of heart with some of the parts due to sourcing
    [LED_Driver.sch, PowerSystem.sch, tl2c.sch]
2016-12-23 Some part changes due to sourcing
    [PowerSystem.sch, tl2c.kicad_pcb]
2016-12-23 Split the board to two separate boards one 2layer the other 4layer
    [tl2c_240v.kicad_pcb, tl2c_ctrl.kicad_pcb]
2016-12-24 Revamped the master pcb layout for the mounting holes and the actual footprint for the terminal blocks
    [PIR13.sch, tl2c.kicad_pcb, tl2c.sch]
2016-12-26 Fixed junction on three wires instead of two, two wire connections. Added first look at the Gerbers
    [tl2c-B.Cu.gbr, tl2c-B.Mask.gbr, tl2c-B.Paste.gbr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]
2016-12-26 Corrected the Ub+ to the LV board... should be U+
    [tl2c.kicad_pcb, tl2c.sch]
2016-12-29 The intial re-hash of the layout for the selected case
    [tl2c.kicad_pcb, tl2c_mastersheet_v1.kicad_pcb]
2016-12-30 More rework on the board for the correct terminal blocks and case
    [tl2c.kicad_pcb, tl2c.sch]
2016-12-31 More layout re-work and footprint changes
    [LED_Driver.sch, PIR13.sch, PowerSystem.sch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]
2016-12-31 Finished off the refactoring for the housing and terminal blocks
    [PIR13.sch, tl2c.kicad_pcb, tl2c.sch]
2017-01-02 Included a small fuse on the Active. Finalised the board
    [tl2c.kicad_pcb, tl2c.sch]
2017-01-02 Added the Reichelt-PN to the fuse for the last commit
    [tl2c.sch]
2017-01-05 Finilised the layout with a larger pin header to expose spare pins to relay driver board
    [LED_Driver.sch, tl2c.kicad_pcb, tl2c.sch]
2017-01-05 Created the Gerbers and submitted the order for boards and stensils
    [tl2c.kicad_pcb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]
2017-01-27 Updated the footprint for the relay - larger holes
    [tl2c.kicad_pcb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]
2017-02-04 Altered the fuse footprint to accomdate the fulse holder instead of the part
    [tl2c.kicad_pcb]
2017-02-17 Fixed some issues with the schematic and layout
    [LED_Driver.sch, PIR13.sch, PowerSystem.sch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]
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2017-03-27 Made a correction to a net label
    [LED_Driver.sch, PIR13.sch, PowerSystem.sch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]
2017-03-30 Finalised the corrections to the board
    [LED_Driver.sch, PIR13.sch, PowerSystem.sch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]
2017-04-22 Corrected the label on the ISP Power connector
    [tl2c.kicad_pcb]
2017-04-25 Finalised the layout/footprint changes for the 240V board
    [tl2c.kicad_pcb, tl2c_240v.kicad_pcb]
2017-04-29 Corrected an issue with the status register
    [main.c]
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2017-05-11 Updated the datasheet to include the interrupt flag in the status register
2017-05-16 Corrected some small issues with the interrupt signalling
    [main.c]
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2017-06-19 Started the Rpi Adapter
    [LED_Driver.sch, PIR13.sch, PowerSystem.sch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]
2017-06-19 Layout done and 2L_1 is sent to OSH Park
    [Rpi_Adapter-B_Cu.gbr, Rpi_Adapter-B_Mask.gbr, Rpi_Adapter-B_SilkS.gbr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]
2017-06-20 Set the Rx and Tx resistors together incase of swapping
    [Rpi_Adapter.kicad_pcb]
2017-07-06 Small changes to the clearances
    [Rpi_Adapter.kicad_pcb, tl2c.kicad_pcb, tl2c.sch]
2017-07-16 Started Hutschiene design
    [LED_Driver.sch, PIR13.sch, PowerSystem.sch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]
2017-07-16 Continuing with the Hutschiene design and layout
    [LED_Driver.sch, PIR13.sch, PIR_Connector.sch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]
2017-07-17 Further work on the redesign
    [LED_Driver.sch, PIR13.sch, PIR_Connector.sch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]
2017-07-19 Further work on the new Hutschiene Layout
    [LED_Driver.sch, PIR13.sch, PIR_Connector.sch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]
2017-07-19 Further to the layout for the Hutschiene
    [tl2c.kicad_pcb, tl2c.sch]
2017-07-19 Hutschiene layout intermediate save
    [tl2c.kicad_pcb, tl2c.sch]
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2017-07-23 Completed draft of hutshiene layout
    [tl2c.kicad_pcb, tl2c.sch]
2017-07-24 Reworked the layout for the CamdenBoss enclosure
    [tl2c.kicad_pcb]
2017-07-24 Adjusted the size and location of the terminal blocks
    [PIR_Connector.sch, tl2c.kicad_pcb, tl2c.sch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]
2017-07-31 Final adjustments for the seperation and push to OSH Park
    [tl2c.kicad_pcb]
2017-07-31 Pushed the boards to OSHPark
    [tl2c.kicad_pcb, tl2c_240v.kicad_pcb, tl2c_ctrl.kicad_pcb]
2017-08-02 Corrections to the terminal block drill holes
    [tl2c.kicad_pcb, tl2c_240v.kicad_pcb, tl2c_ctrl.kicad_pcb]
2017-08-08 Re-worked the RPi Adapter to be more compact.
    [Rpi_Adapter-B_Cu.gbr, Rpi_Adapter-B_Mask.gbr, Rpi_Adapter-B_SilkS.gbr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]
2017-08-19 Reworked the RPi Adapter 2L_4 for RJ45
    [Rpi_Adapter.kicad_pcb, Rpi_Adapter.sch]
2017-08-20 Flipped the RJ45 to the bottom
    [tl2c.kicad_pcb]
2017-08-23 Flipped the programming head to the bottom
    [tl2c.kicad_pcb]
2017-08-26 Flipped the programming header to the bottom (correct layout)
    [tl2c.kicad_pcb]
2017-08-26 Flipped the programming header properly
    [tl2c.kicad_pcb]
2017-08-26 Fixed some labels and text
    [tl2c.kicad_pcb]
2017-08-30 Correction to the board connected and seperated out the pwr
    [LED_Driver.sch, PIR13.sch, PIR_Connector.sch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]
2017-09-13 More refinements based on the DIN prototype tests
    [LED_Driver.sch, PIR13.sch, PIR_Connector.sch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]
2017-09-17 Enhancements to the RPi Adapter and DIN boards
    [Rpi_Adapter.kicad_pcb, tl2c.kicad_pcb]
2017-09-18 In preperation for using a stencil - moved most 0805 back from handsolder to normal
    [LED_Driver.sch, PIR13.sch, PowerSystem.sch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]
2017-10-05 Corrected issues with the connectors - Pushing to OSH Park
    [tl2c.kicad_pcb, tl2c.sch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]
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2017-10-17 Commiting the gerbers for the Rpi RJ45 adapter
    [Rpi_Adapter-B_Cu.gbr, Rpi_Adapter-B_Mask.gbr, Rpi_Adapter-B_SilkS.gbr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]
2017-10-30 Moved the RJ45 for the back-plane placement
    [LED_Driver.sch, PIR13.sch, PIR_Connector.sch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]
2017-11-26 Reduced the size of the Rpi_Adapter to make a better fit into the enclosure
    [Rpi_Adapter.kicad_pcb]
2017-11-27 Radically reduced the size of the board
    [Rpi_Adapter-B.Cu.gbr, Rpi_Adapter-B.Mask.gbr, Rpi_Adapter-B.SilkS.gbr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]
2019-04-16 Upgrade to KiCad 5.1
    [LED_Driver-2019-01-25-19-11-47.sch, LED_Driver-2019-02-24-18-13-08.sch, LED_Driver-2019-02-24-18-13-34.sch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]
2024-02-06 Bringing the board into the latest KiCad
    [LED_Driver.kicad_sch, PIR13.kicad_sch, PIR_Connector.kicad_sch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]
2024-07-01 Esp32 (#1)
    * First draft of the esp32 module
    * Created the front panel artwork with drill marks
    * Updated the PDFs
    * Added some comments
    * Pin reassignments after starting the firmware
    * Completed the release for OSH Park
    * Created rev 1.01 - Addes some more labels and annotations
    * Reseated the RJ45
    * Doc update
    * R1 correction
    * Adding some documentation
    * Added some doc
    * changes to help with the writeup
    * Updated the artwork and documentation
    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
    [15-22SURSYGC-B.FCStd, 15-22SURSYGC.FCStd, B3F_1150.step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]
2026-08-06 Merge esp32 changes to the main branch (#2)
    * project upate
    ---------
    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
2026-08-10 Update and archive for kicad 10.0.2
    [Zone_1_Enable.kicad_sch, Zone_2_Enable.kicad_sch, Zone_3_Enable.kicad_sch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]
